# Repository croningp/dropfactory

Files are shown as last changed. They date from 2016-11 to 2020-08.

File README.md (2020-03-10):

> This repository is associated to the paper "A curious formulation robot enables the discovery of a novel protocell behavior" by Grizou, J., Points, L. J., Sharma, A. & Cronin, L. (2020) [[PDF in open Access @ Science Advances]](https://advances.sciencemag.org/content/6/5/eaay4237). An overview of the scientific approach can be found at https://jgrizou.com/projects/chemobot.

# Dropfactory

Dropfactory is a robotic platform able to perform and record oil-in-water droplet experiments at a large scale.

Dropfactory (https://www.youtube.com/watch?v=o8ZTkoZ-j6M)

Dropfactory is capable of running, in total autonomy, an arbitrary droplet experiment lasting 1min30sec every 1min50sec. We routinely performed more than 350 Experiments per working day on this platform. This enabled us to explore the efficiency of exploration and optimization algorithms directly on our physicochemical system, that is directly sampling the real world.

Here is an example of droplet behaviors:

Droplets (https://www.youtube.com/watch?v=ysEswhRS5CQ)

## Principles

The platform is organized as a little factory, enabling us to fully parallelize all required operations (mixing, droplet placing, recording, cleaning, drying). An oil-in-water experiment consists of placing small oil droplets (made from an arbitrary mixture of oils) at the surface of an aqueous medium (made from a mixture of aqueous phases), we then need to video record the droplet movements to later analyse them.

To be able to run continuously such experiments, the platform must be able to mix, sample, clean and dry both oils and aqueous phases. Previous designs had to do all such steps in sequence, Dropfactory does them in parallel thanks to its design around two geneva wheel mechanisms.

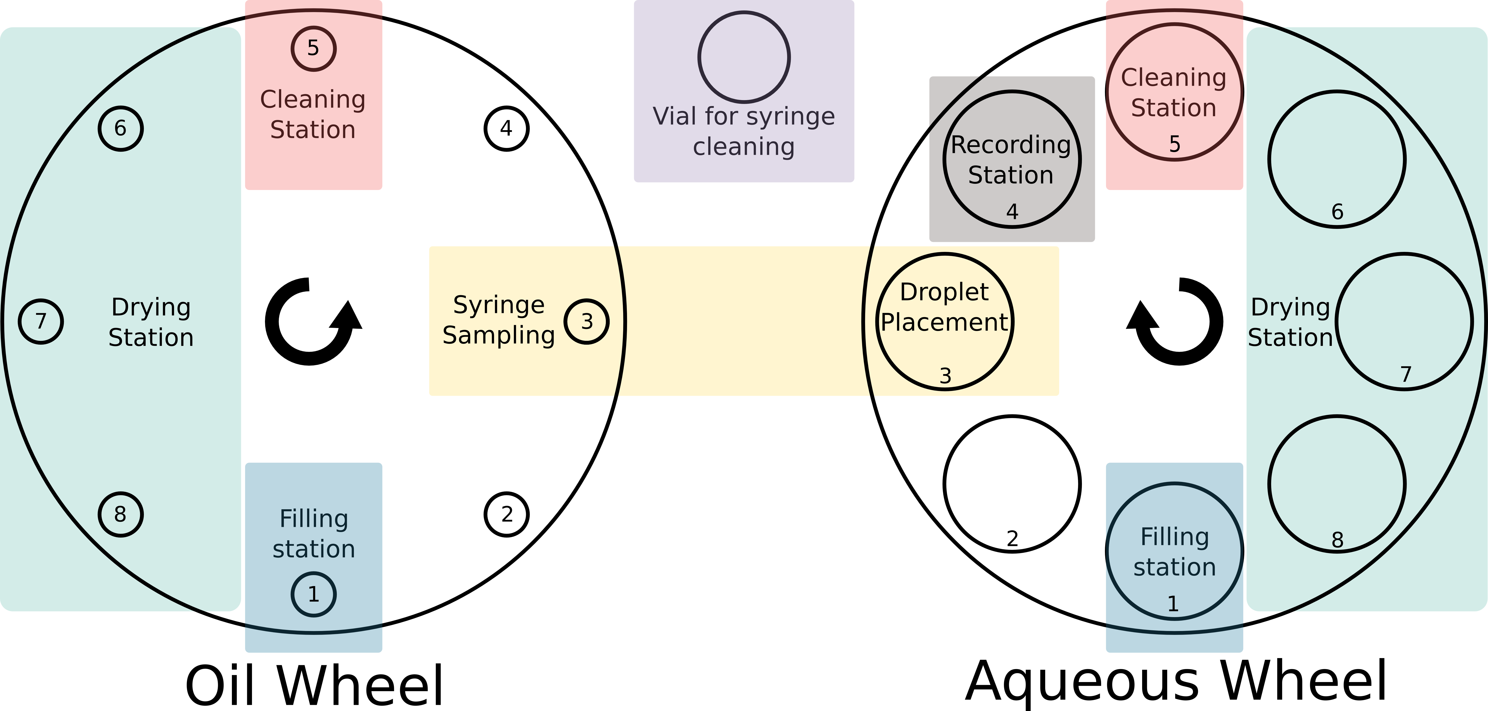
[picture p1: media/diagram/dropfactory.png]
Diagram


This design allows to move the oil vials and the petri dish at specialized working stations, rather than having the tools move to those containers. As a result, Dropfactory is:

- **robust**, because there are much less moving parts. Each working station can perform only its specific task at the location it was designed to work. This means less tubing moving around.
- **easier to maintain**, because all working stations are clearly separated, both physically and digitally, identifying a bug or a mechanical failure is quick and fixing them is easier.
- **fast**, because while an oil mixture is prepared, a previous one is being cleaned, another three are being dried, another is sampled by a syringe to be placed on a previously filled petri dish. At the same time, another petri dish is being filled, one is being cleaned, three are drying, and one contains droplets and is being recorded under a camera.

Dropfactory enables to record 1 experiment of 1min30sec every 1min50sec, gaining a factor of 6 versus our previous sequential platform. Thanks to its robustness, the platform was consistently running for months in the lab collecting more than 30,000 droplet experiments.

Below is a speed up video showing the operation of the parallelized droplet robot with details of each working station. The first few seconds gives a general overview of the working platform, whilst the remainder of the video shows each working station in operation in detail.

Dropfactory_Station (https://youtu.be/bY5OoRBJkf0)

Feel free to watch the [real time video](https://youtu.be/bY5OoRBJkf0) and [a playlist with all indivual station](https://www.youtube.com/playlist?list=PLBppiRCztuKoLdw_cc4hVg8oFJaySeC6U).

## Documentation

A detailed README is available for all folders:

- [doc](doc) folder is the place to start, it explains the logic behind all choices done in Dropfactory and contains the links to the corresponding files
- [software](software) folder holds all the python code to control and send jobs to the platform
- [hardware](hardware) folder holds all the 3D files designed for Dropfactory as well as many links to source its components.
- [media](media) folder contains some useful images and video links of the platform

This repository contains only the hardware and software used to build and operate Dropfactory. It is complemented by:

- [dropfactory_exploration](https://github.com/croningp/dropfactory_exploration) for the algorithms that use the dropfactory platform as a means to sample the real world.
- [dropfactory_analysis](https://github.com/croningp/dropfactory_analysis) for all the analysis and display of the results of our various droplets experiments and algorithms comparison.

## Author

Design and code by [Jonathan Grizou](http://jgrizou.com/) while working in the [CroninGroup](http://www.chem.gla.ac.uk/cronin/).

Thanks to Vasilis Duros and Graham Keenan for proofreading the documentation.

## License

GPL V3 (https://www.gnu.org/licenses/gpl.html)

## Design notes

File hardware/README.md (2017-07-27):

## Hardware

The [3d_parts](3d_parts) folder holds all 3D files (.stl) designed for Dropfactory. The associated [Onshape](https://www.onshape.com/) documents are accessible and fully modifiable here:

- [Platform (Frame + Geneva Wheels)](https://cad.onshape.com/documents/3aeb7616c1e547bfaae38ba3/w/426b95792e7c48a8b6dd7727/e/af7f485263ee4608affce6e3)
- [Working Stations](https://cad.onshape.com/documents/62d832e8b2dc4f2c03b85d68/w/e45d0051d41b139c7004414d/e/f1aad30ed184d979bb4387d0)
- [Geneva Wheel Stabilizer](https://cad.onshape.com/documents/5789121ee4b07256e8184139/w/a0a9bcb1b97b6c43ac68f81e/e/801990910dc3689559c2009a)
- [Printed Petri Dish](https://cad.onshape.com/documents/d83d667301ed3d6595883287/w/9d1d15f4472cf6b16456272f/e/9b20458d466fec9b558cf9b9)

The modular syringe actuator is fully described here: https://github.com/croningp/ModularSyringeDriver

Links and references to most materials used to build the platform are found in [material_references.md](material_references.md)

More details on the principles and inner working of Dropfactory are documented in the [doc](../doc) folder at the root of this repository.

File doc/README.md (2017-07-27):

The goal of this documentation is to give the reader a global understanding of the guiding principles behind the design of Dropfactory. We also aim to provide a more detailed understanding of how all the components in this repository work together.

## Principles

An oil-in-water experiment consists of placing small oil droplets (made from an arbitrary mixture of oils) at the surface of an aqueous medium (made from a mixture of aqueous phases); we then need to video record the droplet movements to later analyse them.

To be able to run continuously such experiments, the platform must be able to mix, sample, clean and dry both oils and aqueous phases. Previous designs had to do all such steps in sequence, Dropfactory does them in parallel. To do so the platform is organized as a little factory, enabling to fully parallelize all required operations (mixing, droplet placing, recording, cleaning, drying).

Diagram

To achieve this, we designed the platform around three important mechanisms:

- a [XYZ CNC frame](cnc_frame.md) that provides both the structural frame and the mechanism to move the syringe around as required to sample oil mixture and place droplets.
- two [geneva wheels](geneva_wheel.md), one for the oils, one for the aqueous phase. They allow to move the containers from one working station to another in a simple and robust way.
- [working stations](working_stations) that perform only one simple task. The vials and dishes are displaced to the working station thanks to the Geneval wheels. Having specialized working station makes the whole system easier to design, build, and fix. In addition, a lot less cables and tubes will be in motion, reducing again the possibility of failure in the system.

In addition, **we made a point to not over-design or over-specify the platform before building it**. Rather we left ourselves room for iterating on the platform while building it and as we encountered problems. For example, most working stations have been redesigned 2 or 3 times after receiving real-world feedback from practical experience.

To achieve this flexibility we based most of our design on [3D printing](https://en.wikipedia.org/wiki/3D_printing) combined with [aluminium profile](http://ooznest.co.uk/V-Slot) technology - enabling us to tune the system on site. This also explains why there is no overall 3D design specifying every detail of the platform down to the last millimetre.

**Dropfactory is a research platform, it has been conceived with modularity in mind** and we encourage the interested reader to adopt a similar approach if they are willing to build their own robot based on our design.

Below are links with more details on each sub-part of Dropfactory:

- [XYZ CNC frame](cnc_frame.md) contains information needed to build and control the XYZ system.
- [Geneva Wheel](geneva_wheel.md) explains how we designed our geneva wheel system, where the 3D files are and where the code for its control is.
- [Modular Linear Actuator](modular_linear_actuator.md) details our small modular syringe system that is used at several places in the platform (syringe + some working stations).
- [Pumps](pumps.md) explain which pumps we are using and how we control them.
- [Working Stations](working_stations) holds all the information about the design of each working station in the platform.

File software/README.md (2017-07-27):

## Software

This code implements and orchestrates all the working stations, that are specialized modules implemented as threads and able to perform one simple task well, into a fully functional platform able to accept experimental files and execute them in a parallel fashion.

The [manager.py](manager.py) file is the entry point and only file to import for using Dropfactory. It contains a ```add_XP(XP_dict)``` function that adds an experimental configuration (```XP_dict```) to the manager. The ```XP_dict``` can be created as showed in [xp_maker.py](tools/xp_maker.py).

### Experiment description

An experiment is fully described by a json file with the following fields. Note that there are helper tools to build such a file in [xp_maker.py](tools/xp_maker.py).

```python
EXAMPLE_XP_DICT = {
    # Dropfactory outputs some informaiton about the experimental conditions, such as the time of the day
    # it was run, the temperature, the humidity. The 'run_info' field tell the platform where to save
    # that information for this particualr experiment. If the experiment video will be stored place in
    # the "xp_folder" folder, a good practice is to save it at the same place.
    # By convention we use RUN_INFO_FILENAME = 'run_info.json' (see software/tools/filenaming.py)
    'run_info': {
        'filename': os.path.join(xp_folder, RUN_INFO_FILENAME)
    },
    # 'min_waiting_time' is the minimum time a dish should stay at any station,
    # this is to ensure proper drying at the drying stations.
    'min_waiting_time': 60,  # in seconds
    # 'video_info' tells the platform how long the record an experiment for and where to save that video.
    # As with he 'run_info' field, it is a good practice is to save it at the same place.
    # By convention we use VIDEO_FILENAME = 'video.avi' (see software/tools/filenaming.py)
    'video_info': {
        'filename': os.path.join(xp_folder, VIDEO_FILENAME)
        'duration': 90  # in seconds
    },
    # 'arena_type' tell what type of dish the experiment should be using. Dish should be changed manually,
    # only one dish type can be present at the same time on the platform and the ARENA_TYPE field should
    # be changed accordingly in software/constants.py. This field is mostly a security/memory field,
    # we never used other dishes that a plain glass petri_dish.
    'arena_type': 'petri_dish',
    # 'oil_formulation' describe the composition of the oil droplets.
    # The number will be normalized to sum to 1.0.
    # The association between the compounds and the associated pumps is defined in software/constants.py.
    # Changes should be reported there accordingly.
    'oil_formulation': {
        'dep': 0.36,
        'octanol': 0.29,
        'octanoic': 0.0,
        'pentanol': 0.33
    },
    ## 'surfactant_volume' how much aqueous phase to pour in the dish
    'surfactant_volume': 3.5,  # in mL
    # 'surfactant_formulation' is similar 'oil_formulation' but for the aqueous phase,
    # which can be a mixture of multiple aqueous phases. The number will be normalized to sum to 1.0.
    # As for oils, the association between the compounds and the associated pumps is defined
    # in software/constants.py. Changes should be reported there accordingly.
    'surfactant_formulation': {
        'TTAB': 1.0
    },
    # 'droplets' is the placement information for droplet, it is a list where each elements
    # corresponds to one droplet. Each droplets is then described by its 'volume' (in uL) and
    # 'position' (in mm relative to the center of the dish). Here we have 4 droplets,
    # one at the center and three equally spread around on a circle of radius 5mm.
    # DEFAULT_DROPLET_VOLUME = 4 uL.
    'droplets': [
        {
            'volume': DEFAULT_DROPLET_VOLUME, # in uL
            'position': [0, 0] # relative position in mm from the dish center
        },
        {
            'volume': DEFAULT_DROPLET_VOLUME,
            'position': [-5, 0]
        },
        {
            'volume': DEFAULT_DROPLET_VOLUME,
            'position': [2.5, 4.33]
        },
        {
            'volume': DEFAULT_DROPLET_VOLUME,
            'position': [2.5, -4.33]
        }
    ]
}
```

### Repository organization

The code is segmented by functionalities as follows:

- [arduino](arduino) holds the firmware for the two arduino boards that are used to control the entirety of the platform. It is based on our [Arduino-CommandTools](https://github.com/croningp/Arduino-CommandTools) that allows to quickly and flexibly prototype Arduino based robots.
- [pump](pump) holds the pump configurations for the 10 Tricontinent C3000 pumps used to handle liquids for droplet experiments. That is oils and aqueous phases + waste management + cleaning liquids (acetone and water). It utilises our easy to use [pycont](https://github.com/croningp/pycont) python library.
- [robot](robot) contains all the utilities to actuate the platform, such as rotating the geneva wheels or precisely pumping and delivering liquids via our syringe systems. It is based on our [commanduino](https://github.com/croningp/commanduino) tool-kit that allows to quickly and flexibly control Arduino based robots through Python.
- [tools](tools) holds various tools used to manage and organize dropfactory. The most important file is [xp_manager.py](tools/xp_manager.py) that orchestrates the parallelized operation of the robot.
- [webcam](webcam) contains the camera configuration for the MICROSOFT 6CH-00002 we use to video record the droplets. It is based on our [chemobot_tools](https://github.com/croningp/chemobot_tools) library used to detect and analyse droplets.
- [working_station](working_station) contains all the individuals working station that fulfil a single task such as cleaning the oil containers, or placing droplet with the syringe. Those stations are implemented as threads and orchestrated by the [xp_manager.py](tools/xp_manager.py) in the [tools](tools) folder.

Finally the remaining files are helpers I used while developing the platform.

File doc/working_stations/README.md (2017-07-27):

## Working stations

The platform is organized as a little factory, enabling us to fully parallelize all required operations (mixing, droplet placing, recording, cleaning, drying). An oil-in-water experiment consists of placing small oil droplets (made from an arbitrary mixture of oils) at the surface of an aqueous medium (made from a mixture of aqueous phases), we then need to video record the droplet movements to later analyse them.

To be able to run continuously such experiments, the platform must be able to mix, sample, clean and dry both oils and aqueous phases. Previous designs had to do all such steps in sequence, Dropfactory does them in parallel thanks to its design around two geneva wheel mechanisms.

Diagram

The working stations are as follows:

- [Oil filling station](oil_filling.md) prepares the correct mixture of oils in a small vial. Position 1 of the oil wheel.
- [Dish filling station](dish_filling.md) prepares the correct mixture of aqueous phase into the petri dish.  Position 1 of the aqueous wheel.
- [Oil stirring station](oil_stirring.md) makes sure the oils are properly mixed with magnetic stirrers. Position 3 of the oil wheel.
- [Droplet Placement](syringe.md) utilizes a syringe to sample the oils and dispenses them as droplet on the surface of the aqueous phase of the petri dish . Droplet sampling and placement are done on position 3 of their respective wheel.
- [Dish recording](dish_recording.md) simple record using a webcam the droplet behaviour following placement. Position 4 of the aqueous wheel.
- [Oil cleaning recording](oil_cleaning.md) cleans the oil vial so it can be reused in the next round. Position 5 of the oil wheel.
- [Dish cleaning recording](dish_cleaning.md) cleans the petri dish so it can be reused in the next round. Position 5 of the aqueous wheel.
- [Drying stations](drying.md) simply blows air on the cleaned containers to ensure they are totally dry for the next run. Drying is done on position 6, 7 and 8 of each wheel.

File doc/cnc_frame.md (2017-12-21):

## XYZ CNC Frame

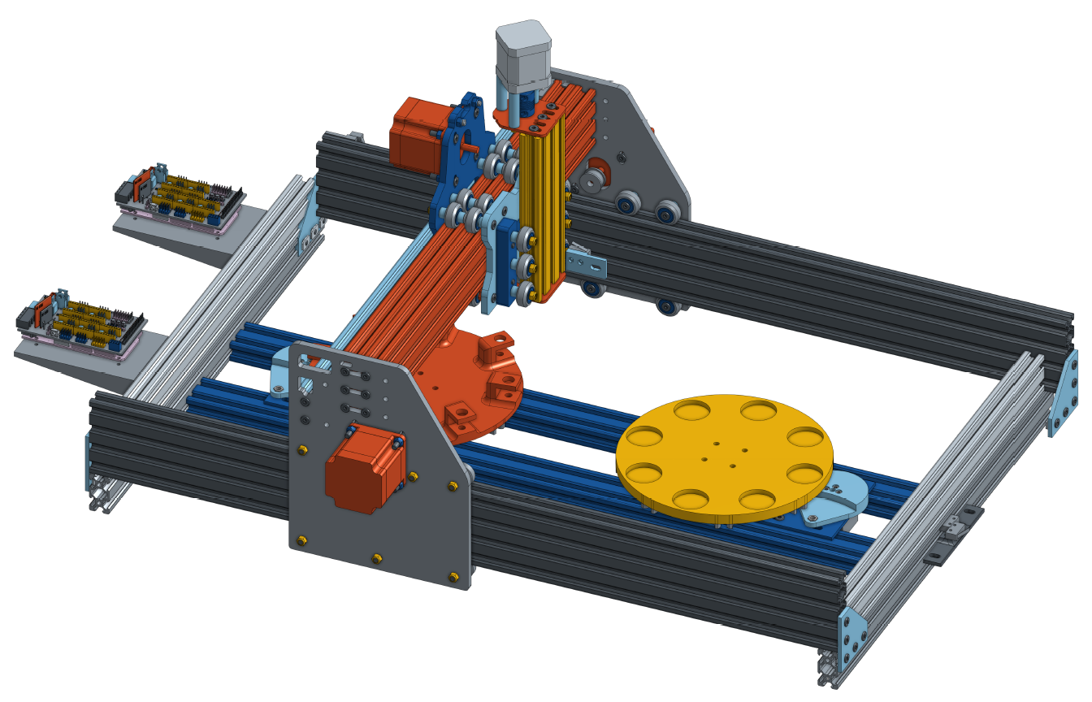
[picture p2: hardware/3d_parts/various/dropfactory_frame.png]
Frame


The XYZ is an open source CNC frame built from [aluminium profiles](http://ooznest.co.uk/V-Slot). We use the [OX CNC MECHANICAL KIT (500x750mm) + 4 NEMA 23 Stepper](http://ooznest.co.uk/3D-Printer-CNC-Kits-Bundles/OX-CNC-Machine/OX-CNC-Mechanical-Kit).

To control the XYZ motion we use two [Arduino Mega boards mounted with a Ramps 1.4 shield](http://ooznest.co.uk/3D-Printer-Electronic-Parts/RAMPS-14-Controller-Board-Premium). Each board can control 5 stepper motors, 3 are needed for the XYZ motion. 1 is needed to control our [syringe system](modular_linear_actuator.md), and 3 more to control some of our [working stations](working_stations). The board also controls our [temperature and humidity sensor](https://www.sparkfun.com/products/13683) that records the conditions under each experiment was performed.

The platform is controlled via python on an external computer using our [commanduino tool-kits](https://github.com/croningp/commanduino) allowing to quickly iterate and prototype Arduino based robots:

- the firmware for both Arduino boards is in the [software/arduino](../software/arduino) folder
- the corresponding python robot controller is in the [software/robot](../software/robot) folder

The frame design and 3D files are [available on Onshape]( https://cad.onshape.com/documents/3aeb7616c1e547bfaae38ba3/w/426b95792e7c48a8b6dd7727/e/af7f485263ee4608affce6e3)

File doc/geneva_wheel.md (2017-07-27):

## Geneva Wheels

Two Geneva wheels (1 for the oil, 1 for the aqueous phase) are at the center of the [XYZ CNC frame](cnc_frame.md), they enable to mechanically move the containers to their working station.

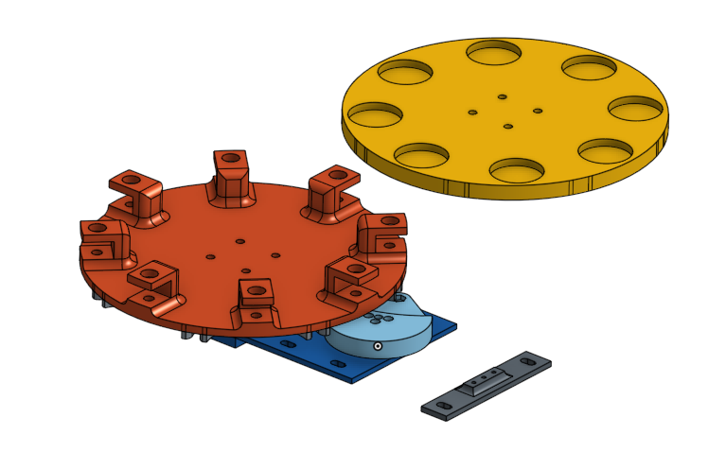
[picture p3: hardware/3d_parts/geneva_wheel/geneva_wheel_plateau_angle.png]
Genava Wheel Angle


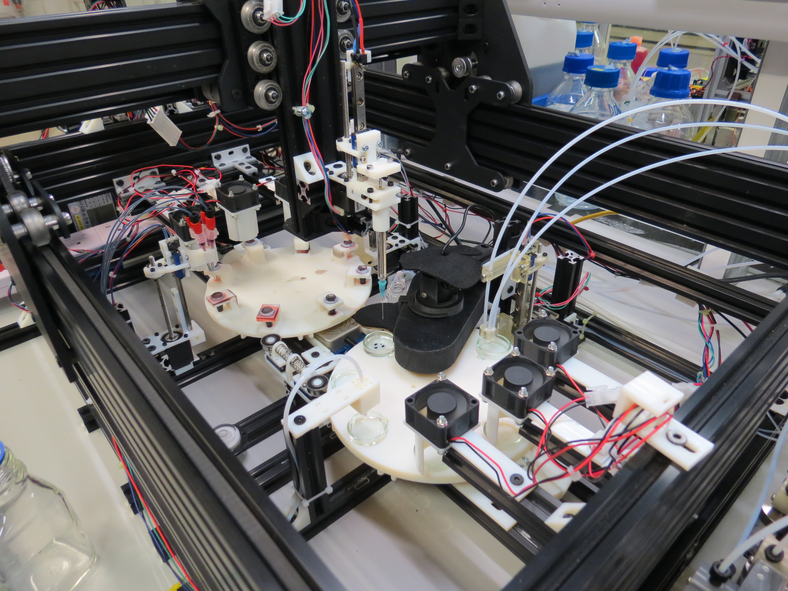
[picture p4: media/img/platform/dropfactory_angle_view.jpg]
Genava Wheel Real


### Principle

The mechanism driving a Geneva wheel provides a robust way to precisely turn a plateau step by step for a given angle from a continuous motion of the driving motor. Importantly, the plateau is mechanically locked into position between each turn. The principle is visualized in the animation below.

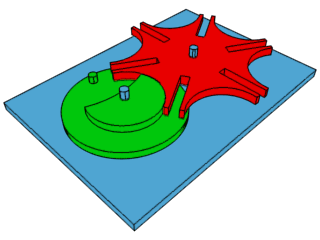
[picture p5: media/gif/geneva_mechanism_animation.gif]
Genava Wheel Gif


By <a href="//commons.wikimedia.org/wiki/User:Mike1024" title="User:Mike1024">Mike1024</a> - Transferred from <span class="plainlinks"><a class="external text" href="//en.wikipedia.org">en.wikipedia</a></span> to Commons., Public Domain, <a href="https://commons.wikimedia.org/w/index.php?curid=561907">Link</a>

Useful links:

- Wikipedia page: https://en.wikipedia.org/wiki/Geneva_drive
- Design principles:  https://newgottland.com/2012/01/08/make-geneva-wheels-of-any-size/
- Dimensioning helper: http://benbrandt22.github.io/genevaGen/

### Design

We designed our Geneva wheel system to be modular, compact, and at the same scale as our aluminium profile system, that is by multiple of 20mm.

The basic Geneva module utilizes a stepper motor that rotates the driving wheel. The rotating shaft/plateau is dimensioned to have 8 steps per turn and has some fixation patterns enabling to mount different types of plateau on top of the wheel.

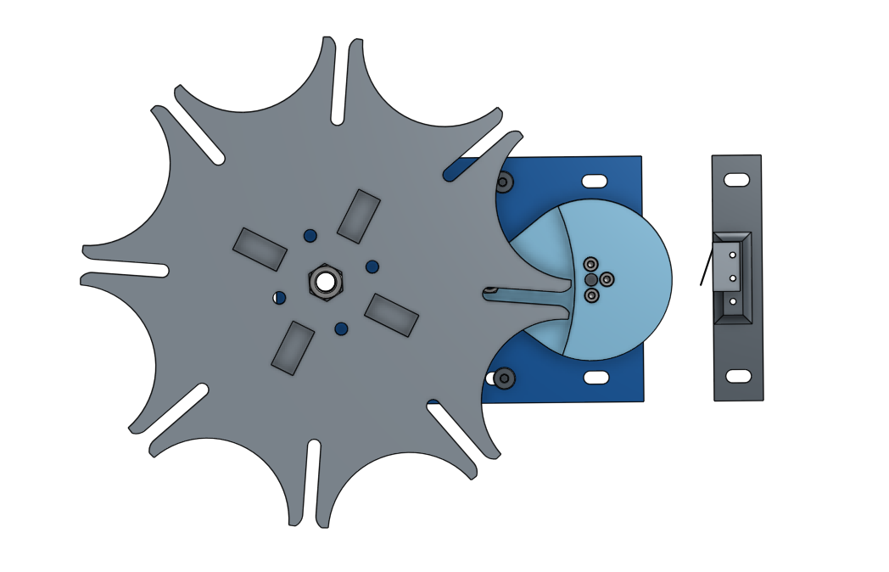
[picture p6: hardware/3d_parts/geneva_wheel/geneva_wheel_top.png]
Geneva Module Top


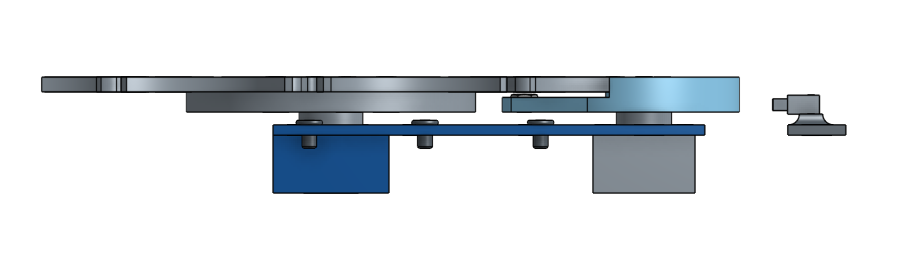
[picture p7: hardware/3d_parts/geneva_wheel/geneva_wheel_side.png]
Geneva Module Side


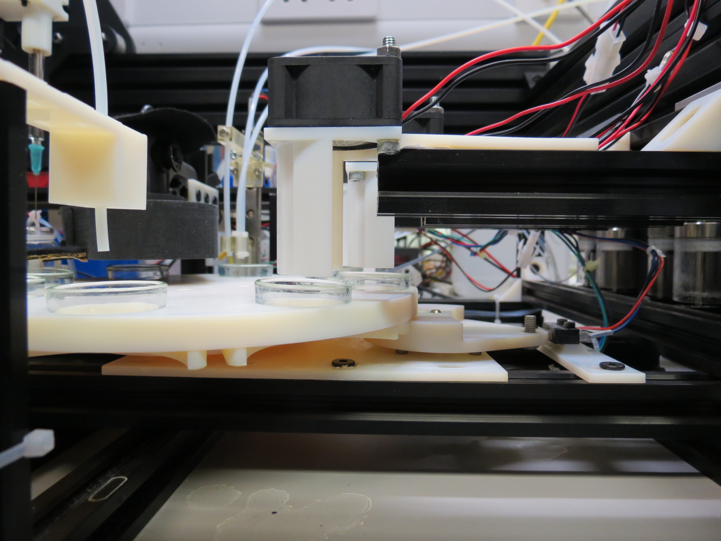
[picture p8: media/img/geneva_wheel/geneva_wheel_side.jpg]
Geneva Module Side Real


We designed two plateaus, one for handling the oil containers and one for holding the petri dishes.

Genava Wheel Angle

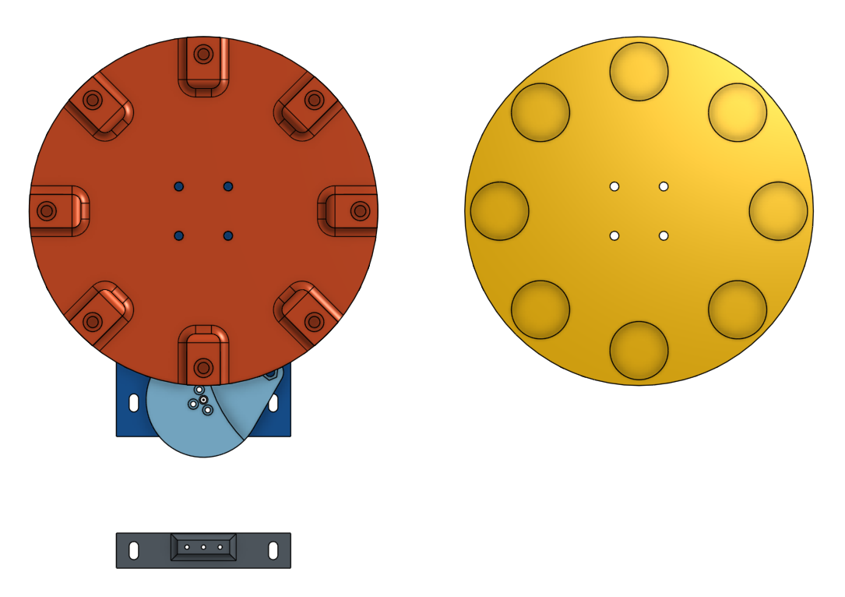
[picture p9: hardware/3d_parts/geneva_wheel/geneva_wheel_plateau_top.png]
Genava Wheel Top


Finally, to improve the smoothness of the motion we designed a stabilizer that comes into contact with both wheel and dampens possible jerks in the wheel motion. The stabilizer is made of two bearings on a sliding axis that are pushed against one another and contact with the side of the Geneva wheels, providing a slight damping that is enough to stabilize the motion.

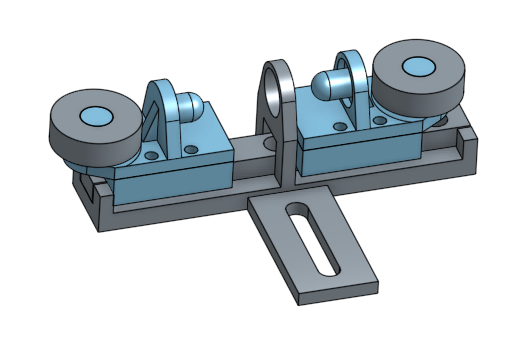
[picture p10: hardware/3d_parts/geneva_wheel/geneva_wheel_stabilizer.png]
Stabilizer


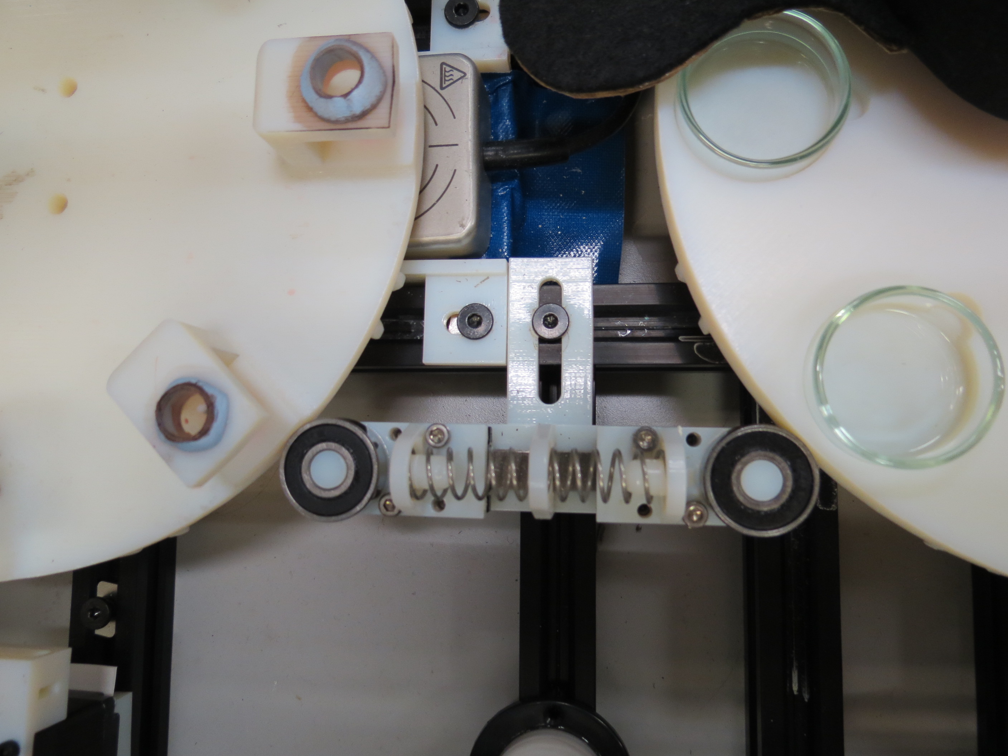
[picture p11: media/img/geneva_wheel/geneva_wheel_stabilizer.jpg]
Stabilizer Real


### Sources

All the 3d stl files are located in the [hardware/3d_parts/geneva_wheel](../hardware/3d_parts/geneva_wheel) folder, along with some visualisation of the parts.

The CAD design file are available on Onshape:

- [Geneva Wheel](https://cad.onshape.com/documents/3aeb7616c1e547bfaae38ba3/w/426b95792e7c48a8b6dd7727/e/30b62a18352c4a91b6bc9828)
- [Geneva Wheel Stabilizer](https://cad.onshape.com/documents/5789121ee4b07256e8184139/w/a0a9bcb1b97b6c43ac68f81e/e/801990910dc3689559c2009a)

The code controlling the synchronous rotation of both wheels is in the [software/robot/robot.py](../software/robot/robot.py) file, more specifically the `rotate_geneva_wheels()` function. That function first makes sure nothing is in the way of the Geneva wheels, then moves the driving stepper motor one full turn, which in turn produces a 1/8 rotation of the plateau. We ensure thhat the stepper actually does one turn by using a homing switch and raise an error if the stepper does not reach the switch within 30 seconds, indicating that the system got stuck somehow.

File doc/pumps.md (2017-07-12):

## Pumps

The platform needs to handle various liquids such as oils, aqueous phases and acetone. Our group is using [Tricontinent C-Series Syringe Pumps](https://www.tricontinent.com/products/syringe-pumps-and-rotary-valves/c-series-syringe-pumps.html). Dropfactory uses 10 of them.

Here is a top view of the pumps and the reageant containers:

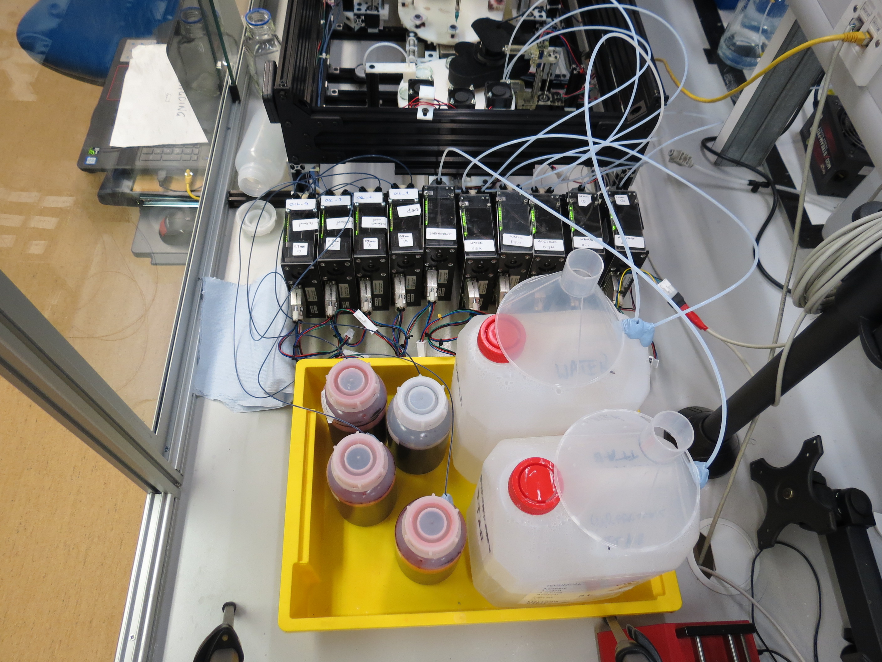
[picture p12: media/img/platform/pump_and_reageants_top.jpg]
Pumps Top


### Pump control

A full documentation of our python library to control the pumps and how to wire them is available at: https://github.com/croningp/pycont

For Dropfactory, the pumps configuration and control is managed in the [software/pump](../software/pump) folder.

### Pumps details

A pump is made of a syringe, whose volume can vary, and a valve that can dispatch the liquid from different directions.

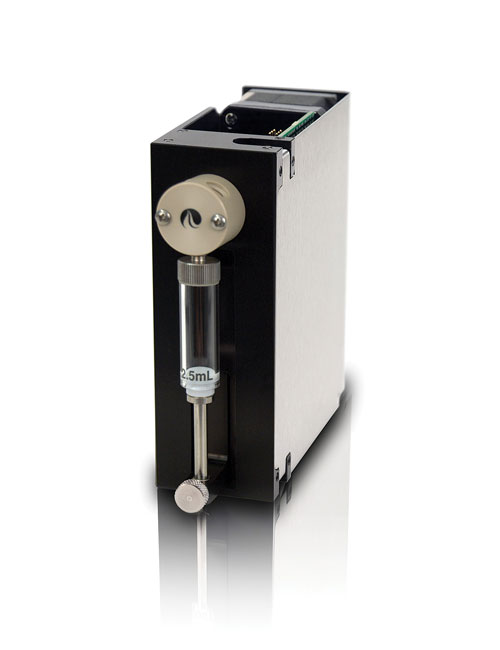
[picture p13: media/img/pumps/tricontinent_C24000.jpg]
Single Pump


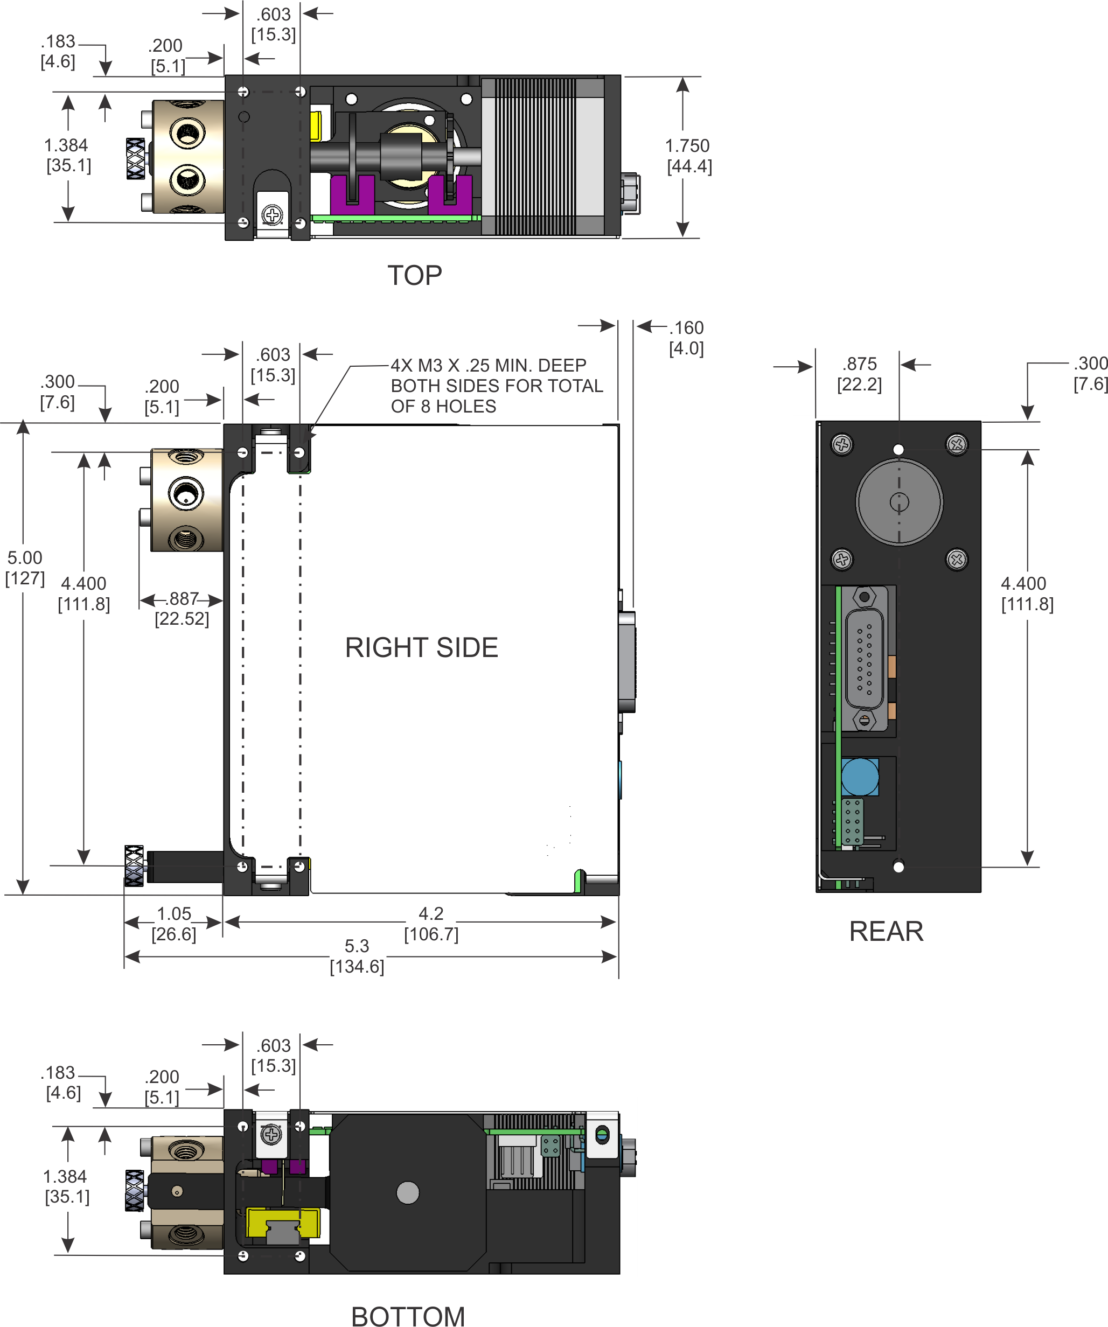
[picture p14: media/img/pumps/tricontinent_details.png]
Specs Pump


### Tubing

Here is some information about the tubing that connects to the pumps

#### Big:

1/8 inch outer diameter tubing and their fitting

- http://kinesis.co.uk/products/fittings-tubing/tubing/tubing-tubing-ptfe-1-8-3-2mm-od-x-1-5mm-id-10m-008t32-150-10.html
- http://kinesis.co.uk/flangeless-fitting-for-1-8-od-tubing-1-4-28-flat-bottom-delrin-etfe-black-yellow-xp-308.html

#### Small:

1/16 inch outer diameter tubing and their fitting

- http://kinesis.co.uk/products/fittings-tubing/tubing/tubing-tubing-ptfe-1-16-1-6mm-od-x-1-0mm-id-20m-008t16-100-20.html
- http://kinesis.co.uk/flangeless-fitting-for-1-16-od-tubing-1-4-28-flat-bottom-delrin-etfe-black-blue-xp-208.html

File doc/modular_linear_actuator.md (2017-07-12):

## Modular Linear Actuator

A full documentation of our small modular linear actuator is available on the following repository: https://github.com/croningp/ModularSyringeDriver

The appeal of this device is its modularity. Many different additions can be designed and printed as can be seen on the illustration below:

Modular Actuator Split View

This actuator is used multiple times in Dropfactory in:

- the [syringe system](working_stations/syringe.md)
- the [oil filling station](working_stations/oil_filling.md)
- the [oil cleaning station](working_stations/oil_cleaning.md)
- the [dish cleaning station](working_stations/dish_cleaning.md)

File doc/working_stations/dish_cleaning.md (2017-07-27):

## Dish Cleaning

This station handles three tubes, one to dispense water, one to dispense acetone, and one to empty the dish content to the waste. This later needs to be dipped into the dish, we use our [modular_linear_actuator](../modular_linear_actuator.md) for that.

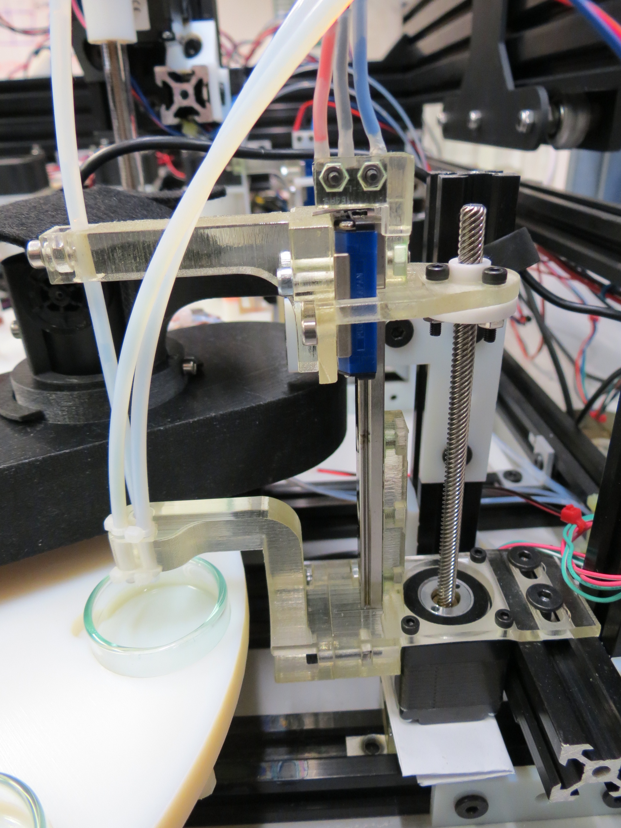
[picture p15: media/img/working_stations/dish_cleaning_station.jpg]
Dish Cleaning Real


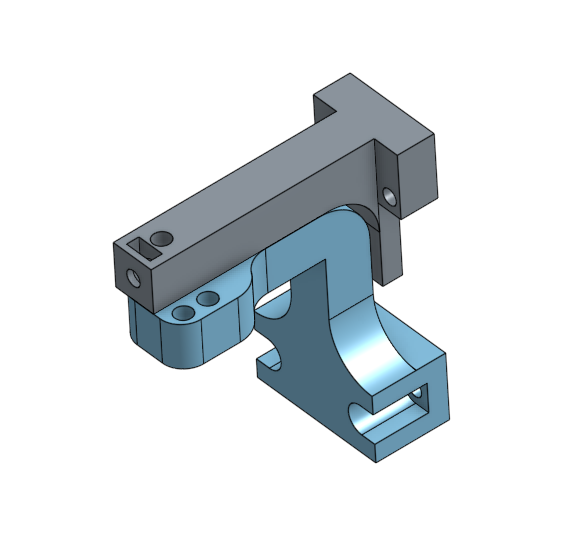
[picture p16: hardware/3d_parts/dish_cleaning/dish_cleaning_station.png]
Dish Cleaning 3D


### Procedure

A petri dish is cleaned using the following protocol:

- empty petri dish of previous experiment's content
- add 4.5mL of acetone into petri dish
- empty petri dish
- add 4.5mL of water into petri dish
- empty petri dish
- add 4.5mL of acetone into petri dish
- empty petri dish
- add 4.5mL of acetone into petri dish
- empty petri dish

### Sources

### 3D designs

- [STL Mount](../../hardware/3d_parts/dish_cleaning/dish_cleaning_mount.stl)
- [STL Guide](../../hardware/3d_parts/dish_cleaning/dish_cleaning_guide.stl)
- [Modular Actuator](https://github.com/croningp/ModularSyringeDriver)
- [Onshape 3D model](https://cad.onshape.com/documents/62d832e8b2dc4f2c03b85d68/w/e45d0051d41b139c7004414d/e/d76ad1c6bf725a9f379d21d0)

### Code

The code managing the dish cleaning working station is here: [software/working_station/clean_petri_dish.py](../../software/working_station/clean_petri_dish.py).

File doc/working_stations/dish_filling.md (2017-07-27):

## Dish Filling

This station simple holds some tubes on top of the position 1 of the aqueous wheel.

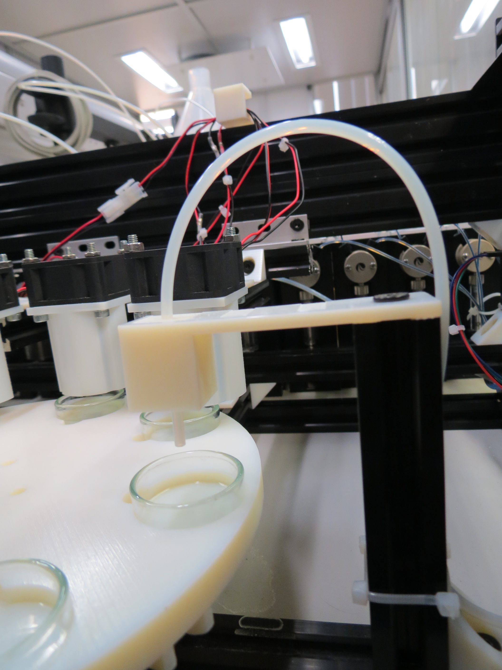
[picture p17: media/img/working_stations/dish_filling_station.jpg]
Dish Filling Real


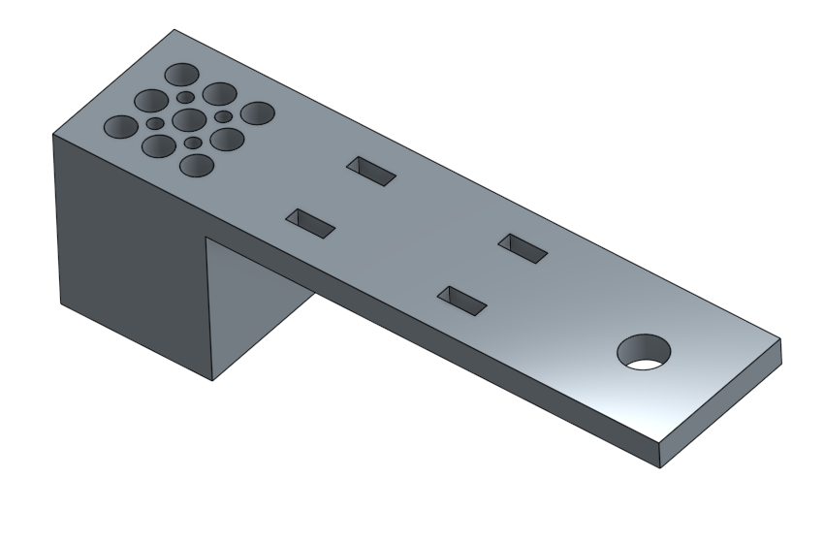
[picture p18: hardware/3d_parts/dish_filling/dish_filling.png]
Dish Filling 3D


In most of our experiments we used only one aqueous phase of TTAB at PH 13.

### Sources

### 3D designs

- [STL](../../hardware/3d_parts/dish_filling/dish_filling.stl)
- [Onshape 3D model](https://cad.onshape.com/documents/62d832e8b2dc4f2c03b85d68/w/e45d0051d41b139c7004414d/e/02edab79fbbeda28022ade23)

### Code

The code managing the dish filling working station is here: [software/working_station/fill_petri_dish.py](../../software/working_station/fill_petri_dish.py).

It simply normalizes the quantity given in the experiment description file (see [software](../../software)) and fills the dish with the given ratios of each aqueous phase given their associated pump and for the defined volume.

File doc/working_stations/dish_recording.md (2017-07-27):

## Dish Recording station

Once the droplets are placed on the aqueous phase, the dish is moved under a camera (position 4 of the aqueous wheel) for the droplet behaviour to be recorded and saved as a video file.

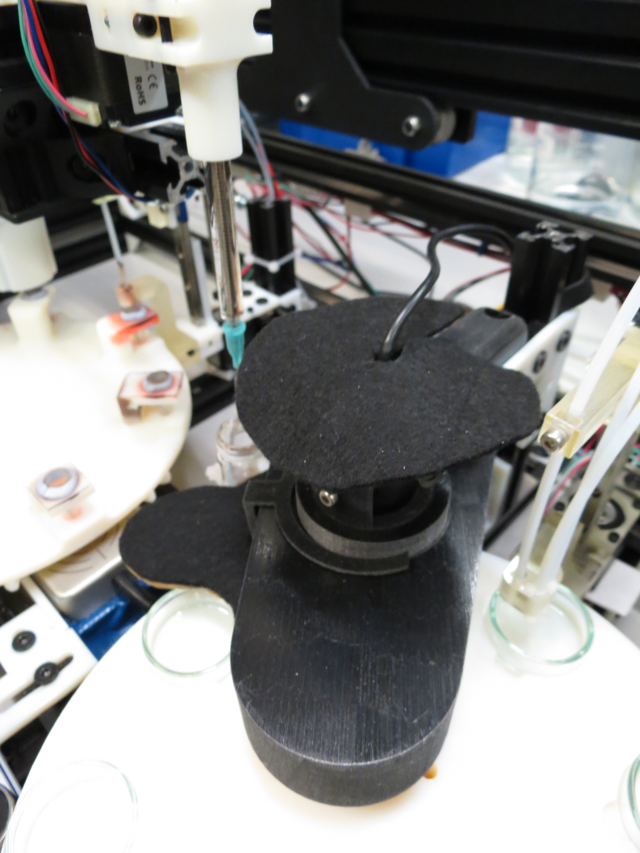
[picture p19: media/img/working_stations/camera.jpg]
Camera Real


We use a simple webcam for recording but we need to ensure that the lighting conditions are very similar between each experiment. Especially, it is important to remove all light reflection on the water surface that hinders the performance of image analysis of the droplets.

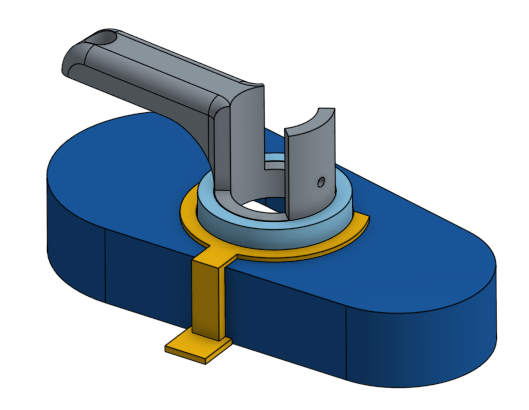
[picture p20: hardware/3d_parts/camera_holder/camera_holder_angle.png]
Camera 3D


### Sources

#### Materials

- [MICROSOFT  6CH-00002](https://www.microsoft.com/accessories/en-gb/business/lifecam-cinema-for-business/6ch-00002)

### 3D designs

- All STL files available in the [hardware/3d_parts/camera_holder](../../hardware/3d_parts/camera_holder) folder
- [Onshape 3D model](https://cad.onshape.com/documents/62d832e8b2dc4f2c03b85d68/w/e45d0051d41b139c7004414d/e/f1aad30ed184d979bb4387d0)

### Code

The code managing the camera working station is here: [software/working_station/record_video.py](../../software/working_station/record_video.py). This simply triggers the recording of a video of given duration into a specified file.

It utilizes tools from our [chemobot_tools](https://github.com/croningp/chemobot_tools) library, and is interfaced and configured in the [software/webcam](../../software/webcam) folder.

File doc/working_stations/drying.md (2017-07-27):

## Drying Station

The drying station is a simple fan blowing air into a container that was previously cleaned with water and acetone. We made sure this additional air flow did not impact our droplet experiments. The drying stations are at the position 6, 7, and 8 of both oil and aqueous wheels.

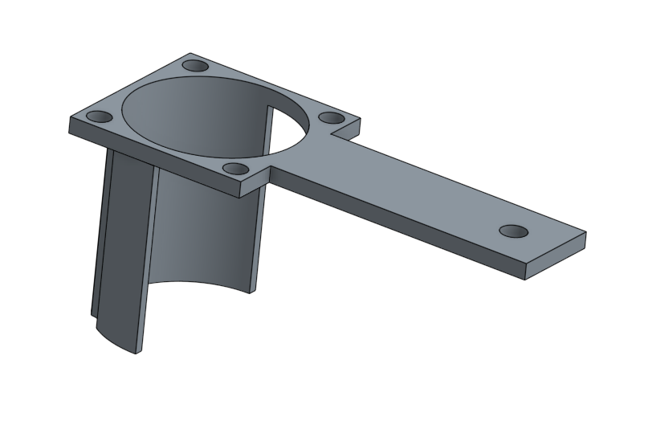
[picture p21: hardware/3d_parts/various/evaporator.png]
Drying STL


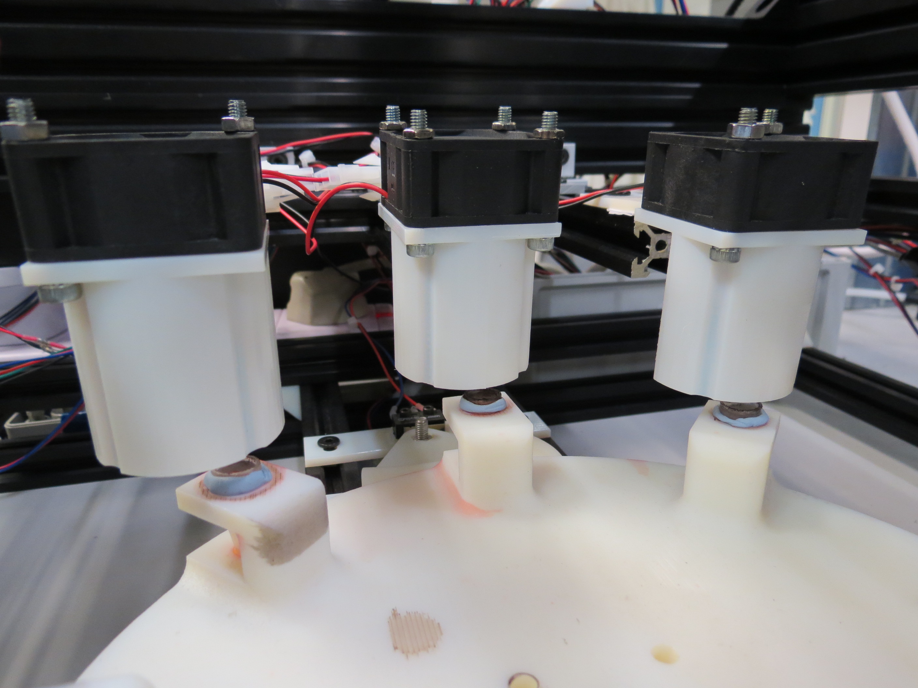
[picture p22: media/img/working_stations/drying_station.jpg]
Drying Real 1


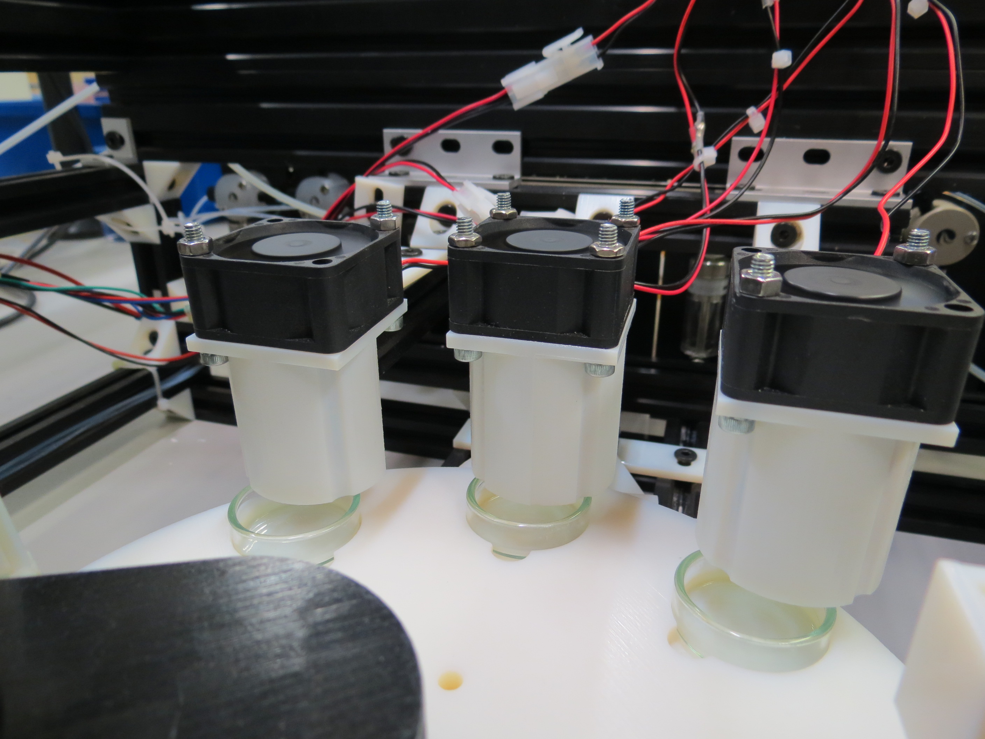
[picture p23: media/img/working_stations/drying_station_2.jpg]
Drying Real 2


### Sources

- [STL](../../hardware/3d_parts/various/evaporator.stl)
- [Onshape 3D model](https://cad.onshape.com/documents/62d832e8b2dc4f2c03b85d68/w/e45d0051d41b139c7004414d/e/ae1bb1b32d86c37772960515)

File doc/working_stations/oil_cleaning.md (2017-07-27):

## Oil Cleaning

This station handles two tubes, one to dispense acetone and one to empty the vials' content to the waste. This later needs to be dipped into the dish, we use our [modular_linear_actuator](../modular_linear_actuator.md) for that.

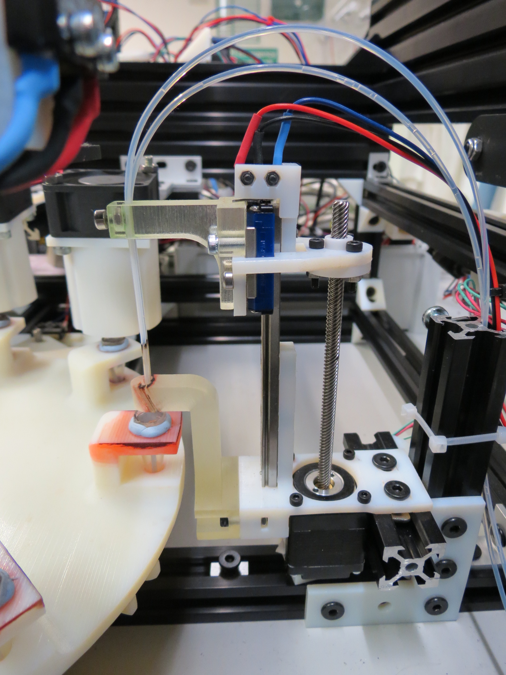
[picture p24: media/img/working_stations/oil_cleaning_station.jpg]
Oil Cleaning Real


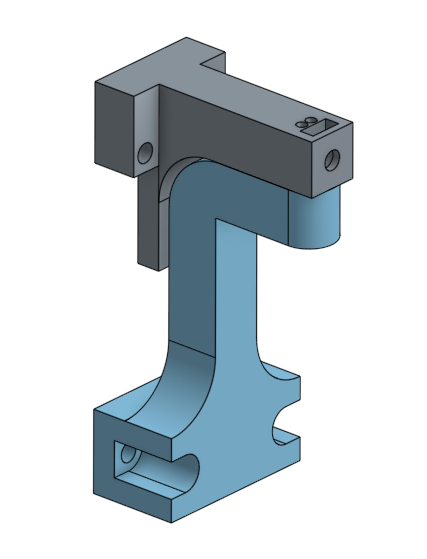
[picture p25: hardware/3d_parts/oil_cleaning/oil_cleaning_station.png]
Oil Cleaning 3D


### Procedure

An oil vial is cleaned usiing the following protocol:

- pump vial content to waste, 2mL (largely exceeding vial volume)
- repeat 5 times:
    - add 0.7mL of acetone into vial
    - pump vial content to waste, 2mL (largely exceeding vial volume)

### Sources

### 3D designs

- [STL Mount](../../hardware/3d_parts/oil_cleaning/oil_cleaning_mount.stl)
- [STL Guide](../../hardware/3d_parts/oil_cleaning/oil_cleaning_guide.stl)
- [Modular Actuator](https://github.com/croningp/ModularSyringeDriver)
- [Onshape 3D model](https://cad.onshape.com/documents/62d832e8b2dc4f2c03b85d68/w/e45d0051d41b139c7004414d/e/ba40210f0cf61fe838ccdc8a)

### Code

The code managing the oil cleaning working station is here: [software/working_station/clean_oil_parts.py](../../software/working_station/clean_oil_parts.py). This file also manages the cleaning of the syringe.

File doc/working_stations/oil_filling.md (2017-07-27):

## Oil Filling

This station handles 4 tubes, one for each of the 4 oils we used in most of our experiments. To ensure accurate dispensing, we lower down the dispnesing head into the vial using our [modular_linear_actuator](../modular_linear_actuator.md).

Oil Filling Real

Oil Filling 3D

### Procedure

- the head is lowered down so the tips of the dispensing needles comes into the vials
- the desired oils are dispensed with a given ratio to a total volume of 0.5mL
- the head is lowered down so the tips of the dispensing needles comes into contact with the surface of the oil mixture, this is to remove any pending drops remaining on the tips of the droplets
- the head comes back to its home position

### Sources

### 3D designs

- [STL Mount](../../hardware/3d_parts/oil_filling/oil_filler.stl)
- [Modular Actuator](https://github.com/croningp/ModularSyringeDriver)
- [Onshape 3D model](https://cad.onshape.com/documents/62d832e8b2dc4f2c03b85d68/w/e45d0051d41b139c7004414d/e/1583bc5599c1a1019a2f3e93)

### Code

The code managing the oil cleaning working station is here: [software/working_station/fill_oil_tube.py](../../software/working_station/fill_oil_tube.py).

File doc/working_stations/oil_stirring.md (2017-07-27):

## Oil Stirring Station

In each oil vial, there is a small magnetic stirrer. At the stirring station (position 3 of the oil wheel) a compact magnetic stirrer ensures that the oils are fully mixed before being sampled by the syringe. Such small magnetic stirrers tend to overheat, for this reason a fan has been positioned below the stirrer to regulate its temperature.

Oil Stirring

### Sources

#### Materials

- [STIRRER MICRO 07 + UK TELEMODUL 7W, from H + P LABORTECHNIK. Supplied at VWR, catalog number is 442-3116]( https://uk.vwr.com/store/product/442-3116/stirrer-micro-07-%2B-uk-telemodul-7w-1-1-items)
- [Stir bars - plain economy 4.0x0.8. Magnetic stirring bars, plain, economy. Supplied from VWR, catalog number is 442-0484](https://uk.vwr.com/store/catalog/product.jsp?catalog_number=442-0484)

#### 3D designs

- [STL Stirrer Holder](../../hardware/3d_parts/oil_mixing/stirrer_holder.stl)
- [STL Stirrer Fan Holder](../../hardware/3d_parts/oil_mixing/stirrer_fan_holder.stl)
- [Onshape 3D model](https://cad.onshape.com/documents/62d832e8b2dc4f2c03b85d68/w/e45d0051d41b139c7004414d/e/7f2bc6ac687a7f6977a3b478)

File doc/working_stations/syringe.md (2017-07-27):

## Syringe

The syringe is used for droplet placements, that is to move to collect the oil mixture, then move to the petri dish and place the droplets and finally cleans itself before moving to the next experiment. The experimental parameters are fully described in the experiment configuration file, see [software](../../software).

Syringe Front

Syringe Model

### Procedures

#### Syringe Oil Filling

- move syringe on top of oil vial (position 3 of oil wheel)
- move syringe down to dip needle into the oil
- repeat 5x: pump and release 50mL of oil mixture, this is to double ensure oils are mixed in addition of the stirrer
- pump 20uL more oil mixture than droplet making requires (total volume of requested droplets)
- move syringe up

#### Droplet Making

- move syringe on top of the center of the petri dish (position 3 of aqueous wheel)
- for each droplet defined in the config file:
    - move to given relative position, making sure it is not outside the petri dish
    - deliver given droplet volume, the droplet should not be released at this point but stick to the needle
    - move syringe down to touch the surface
    - move syringe up again above aqueous phase level
- move syringe up high above

#### Syringe Cleaning

- move syringe on top of the dedicated syringe cleaning vial
- empty syringe in the vial
- wash the vial with 1.5 mL acetone
- add 2.5mL acetone into vial
- dip needle into acetone
- repeat 3x: pump and deliver 100uL of acetone through the syringe, ensuring cleaning of remaining in oil mixture
- move syringe up again above vial
- empty vial of its contents
- repeat 8x: pump and deliver 100uL of air through the syringe, ensuring drying of remaining acetone
- wash the vial with 1 mL acetone

### Sources

### Materials

- our syringe module is compatible with all [uL Hamilton syringes](https://www.hamiltoncompany.com/products/syringes-and-needles/general-syringes/microliter-syringes/250-microL-Model-725-LT-SYR-NDL-Sold-Separately)
- we use dispensing needles of [this serie](http://uk.farnell.com/weller/kds2312p/dispensing-needle-ga23-id-0-43mm/dp/3975630), see [catalog](http://www.farnell.com/datasheets/514885.pdf).

### 3D designs

- [Modular Actuator](https://github.com/croningp/ModularSyringeDriver)
- [STL Cleaning Vial Holder](../../hardware/3d_parts/various/vial_holder.stl)
- [Onshape Cleaning Vial Holder](https://cad.onshape.com/documents/62d832e8b2dc4f2c03b85d68/w/e45d0051d41b139c7004414d/e/640ac0deb1f80bf00c4bdb79)

### Code

The code managing the syringes is split into two files:

- [software/working_station/clean_oil_parts.py](../../software/working_station/clean_oil_parts.py) for cleaning the syringes, this is because the pumps for acetone and waste are shared between the [oil vial cleaning station](oil_cleaning.md).
- [software/working_station/make_droplets.py](../../software/working_station/make_droplets.py) that takes care of the sampling of oils and the droplet placement.

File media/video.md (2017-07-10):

Videos are hosted on Youtube.

Playlist: https://www.youtube.com/playlist?list=PLBppiRCztuKoLdw_cc4hVg8oFJaySeC6U

## Platform at work

- Side View 1: https://www.youtube.com/watch?v=o8ZTkoZ-j6M
- Side View 2: https://www.youtube.com/watch?v=L7Q5ZuYX-jI
- Top View: https://www.youtube.com/watch?v=izmoXcZmUyA

## Individual workstation

- Oil Filling:https://www.youtube.com/watch?v=_yILCzj3Ur8
- Oil Cleaning: https://www.youtube.com/watch?v=vuSbGqEvNPU
- Dish Filling: https://www.youtube.com/watch?v=RBeclG4bZSc
- Dish Cleaning: https://www.youtube.com/watch?v=eZBr9EsQKLc
- Making Droplets: https://www.youtube.com/watch?v=BPY1zyb-Gb0
- Droplet Placement: https://www.youtube.com/watch?v=23sXEIOUkyw
- Syringe Cleaning: https://www.youtube.com/watch?v=D9TM6lLt240
- Pumps In Action: https://www.youtube.com/watch?v=tYG90OaSkag

## Droplets and Previous Robots

- Compilation of Droplets Behaviors: https://www.youtube.com/watch?v=ysEswhRS5CQ
- Compilation of Chemobot Platforms: https://www.youtube.com/watch?v=IiTAi5so2TA

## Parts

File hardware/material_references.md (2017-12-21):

## Generic references

Fully documented subparts:

- Our Modular Syringe Driver: https://github.com/croningp/ModularSyringeDriver
- Our Tricontinent Pump controller: https://github.com/croningp/pycont

## Platform

### Frame and kits

- OX CNC MECHANICAL KIT (500x750mm) + 4 NEMA 23 Stepper: http://ooznest.co.uk/3D-Printer-CNC-Kits-Bundles/OX-CNC-Machine/OX-CNC-Mechanical-Kit

### Control board

- Ramps 1.4, sits on top of an Arduino mega: http://ooznest.co.uk/3D-Printer-Electronic-Parts/RAMPS-14-Controller-Board-Premium?limit=100
- Wiring kit: http://ooznest.co.uk/3D-Printer-Electronic-Parts/RAMPS-1.4-Wiring-Kit?limit=100
- Switch: http://ooznest.co.uk/Micro-Lever-Switch

### Webcam

- MICROSOFT  6CH-00002: http://onecall.farnell.com/microsoft/6ch-00002/webcam-lifecam-cinema-business/dp/CS25782

### Temperature sensor

- SparkFun Humidity and Temperature Sensor Breakout - SHT15: https://www.sparkfun.com/products/13683

### Geneva Wheel

#### Stepper mount:

- https://www.proto-pic.co.uk/pololu-universal-mounting-hub-for-5mm-shaft-m3-holes-2-pack.html
- https://www.pololu.com/file/0J665/1998-5mm-m3-hub-dimensions.pdf

#### Bearings:

- http://uk.rs-online.com/web/p/ball-bearings/6189957/

#### M8 for the axis
- http://uk.rs-online.com/web/p/hex-bolts/7976288/
- http://uk.rs-online.com/web/p/hex-nuts/0530769/

#### M5
- Hex socket button: http://uk.rs-online.com/web/p/socket-screws/2328237

### Guide Chain

- http://uk.rs-online.com/web/p/cable-trunkings/3825385/
- http://uk.rs-online.com/web/p/cable-trunking-accessories/7559091

### Misc

- http://uk.farnell.com/pro-power/cv-100/cable-tie-100mm-pa66-pk100/dp/1416039
- http://uk.farnell.com/hellermanntyton/t50r-nat-100-pack/cable-tie-natural-200mm-pk100/dp/1168937

## Chemistry handling

### Mini Stirrer

- STIRRER MICRO 07 + UK TELEMODUL 7W, from H + P LABORTECHNIK. Supplied at VWR, catalog number is 442-3116: https://uk.vwr.com/store/product/442-3116/stirrer-micro-07-%2B-uk-telemodul-7w-1-1-items
- Magnetic stirring bars, micro. Length: 15mm, Diameter: 1.5mm. Supplied from VWR, catalog number is 442-0367: https://uk.vwr.com/store/catalog/product.jsp?catalog_number=442-0367

### Syringe

Hamilton Microliter syringes
- https://www.hamiltoncompany.com/products/syringes-and-needles/general-syringes/microliter-syringes/700-series/50-microL-Model-705-LT-SYR-NDL-Sold-Separately
- https://www.hamiltoncompany.com/products/syringes-and-needles/syringe-selection-tool/100-microL-m-Model-710-LT-Calibrated-SYR-NDL-Sold-Separately
- https://www.hamiltoncompany.com/products/syringes-and-needles/general-syringes/microliter-syringes/250-microL-Model-725-LT-SYR-NDL-Sold-Separately

### Blunt needle

- http://www.farnell.com/datasheets/514885.pdf
- http://uk.farnell.com/weller/kds2512p/dispensing-needle-ga25-id-0-30mm/dp/3975654
- http://uk.farnell.com/weller/kds2312p/dispensing-needle-ga23-id-0-43mm/dp/3975630

### Petri Dishes

- https://uk.vwr.com/store/catalog/product.jsp?catalog_number=BRND455701
- https://uk.vwr.com/store/catalog/product.jsp?catalog_number=391-2820

## Mixing vials

- https://webshop.fishersci.com/insight2_uk/getProduct.do?productCode=11558232&resultSetPosition=0

### Tubing

#### Big:

1/8 inch outer diameter tubing and their fitting

- http://kinesis.co.uk/products/fittings-tubing/tubing/tubing-tubing-ptfe-1-8-3-2mm-od-x-1-5mm-id-10m-008t32-150-10.html
- http://kinesis.co.uk/flangeless-fitting-for-1-8-od-tubing-1-4-28-flat-bottom-delrin-etfe-black-yellow-xp-308.html

#### Small:

1/16 inch outer diameter tubing and their fitting

- http://kinesis.co.uk/products/fittings-tubing/tubing/tubing-tubing-ptfe-1-16-1-6mm-od-x-1-0mm-id-20m-008t16-100-20.html
- http://kinesis.co.uk/flangeless-fitting-for-1-16-od-tubing-1-4-28-flat-bottom-delrin-etfe-black-blue-xp-208.html

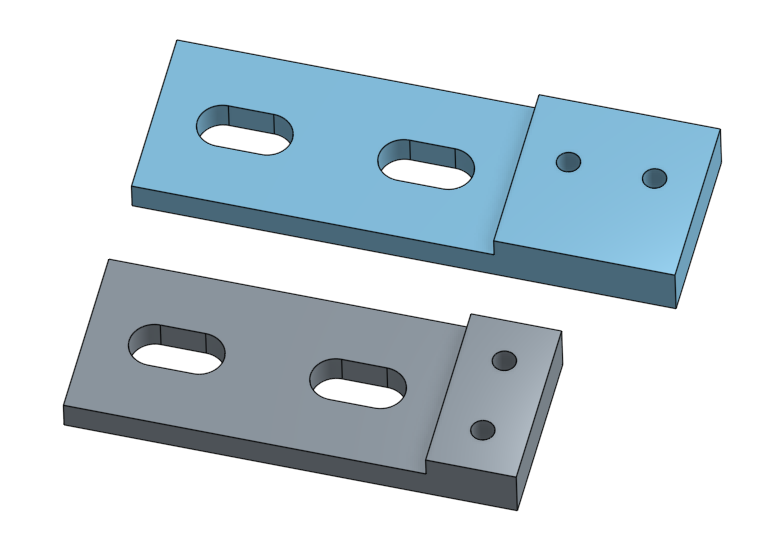
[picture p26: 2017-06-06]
hardware/3d_parts/various/switch_holder_long.png

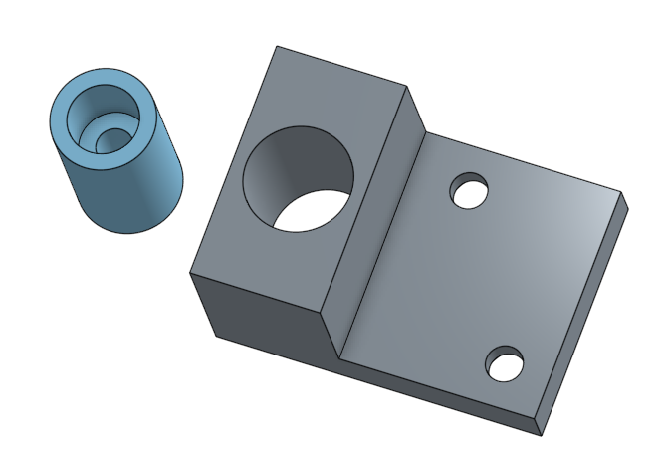
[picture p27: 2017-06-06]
hardware/3d_parts/various/chain_rotation.png

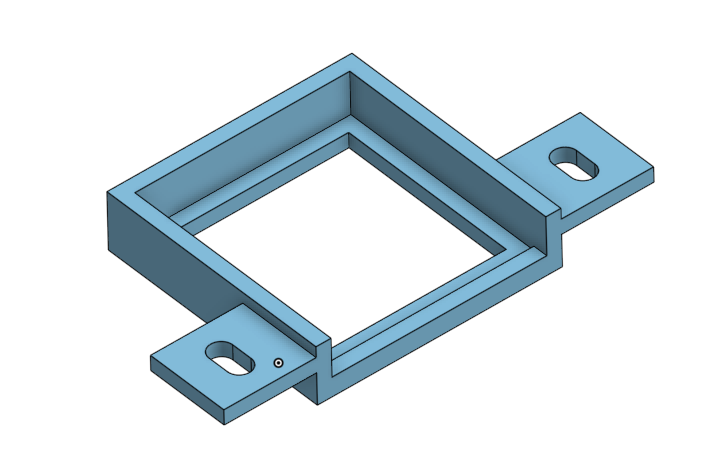
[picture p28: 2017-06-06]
hardware/3d_parts/oil_mixing/stirrer_holder.png

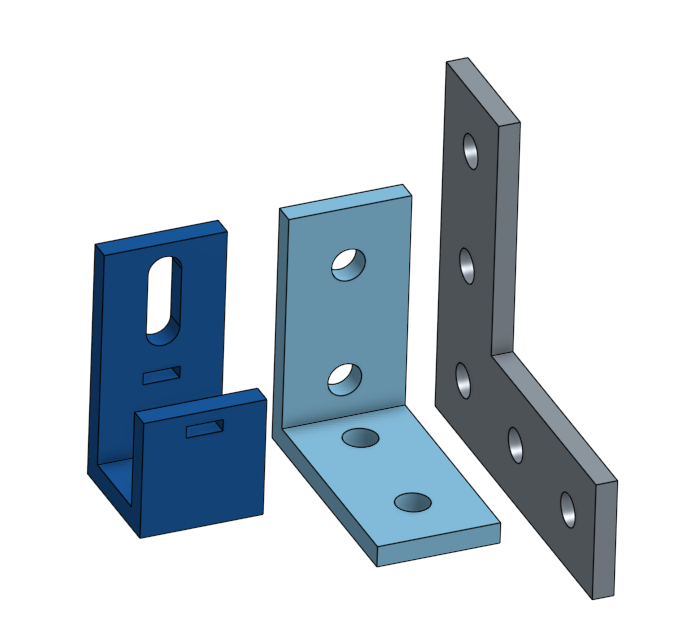
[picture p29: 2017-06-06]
hardware/3d_parts/various/vslot_tools.png

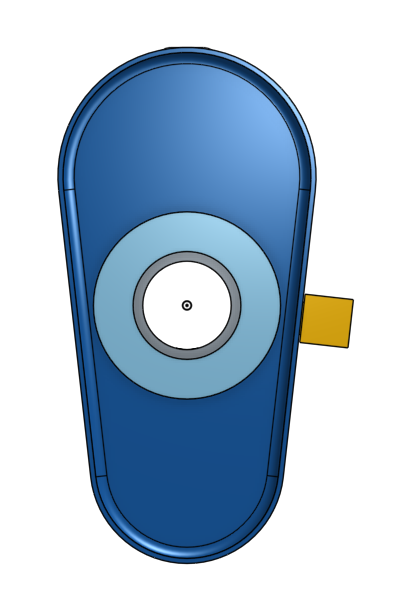
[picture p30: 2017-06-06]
hardware/3d_parts/camera_holder/camera_holder_bottom.png

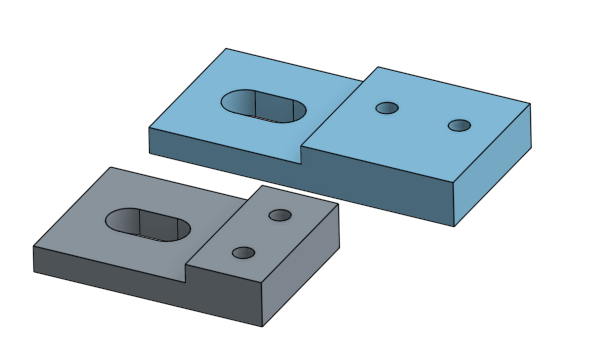
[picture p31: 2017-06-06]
hardware/3d_parts/various/switch_holder_short.png

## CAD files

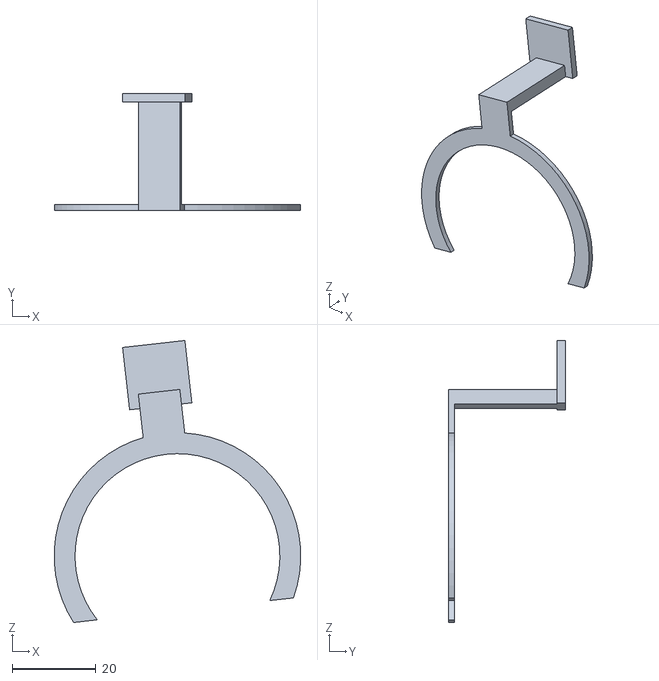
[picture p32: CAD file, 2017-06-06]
hardware/3d_parts/camera_holder/camera_shader_accessory.stl
58.9 x 28.0 x 67.5

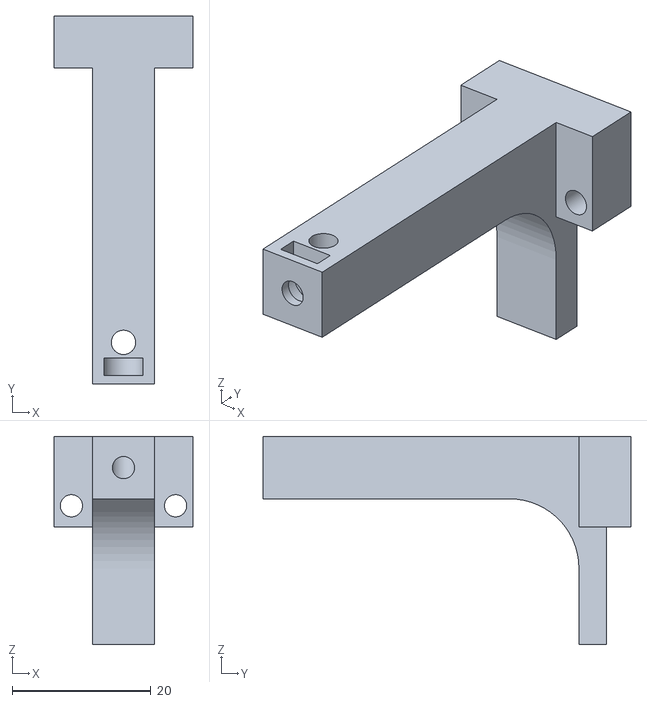
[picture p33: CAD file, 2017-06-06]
hardware/3d_parts/dish_cleaning/dish_cleaning_mount.stl
20.0 x 53.0 x 30.0

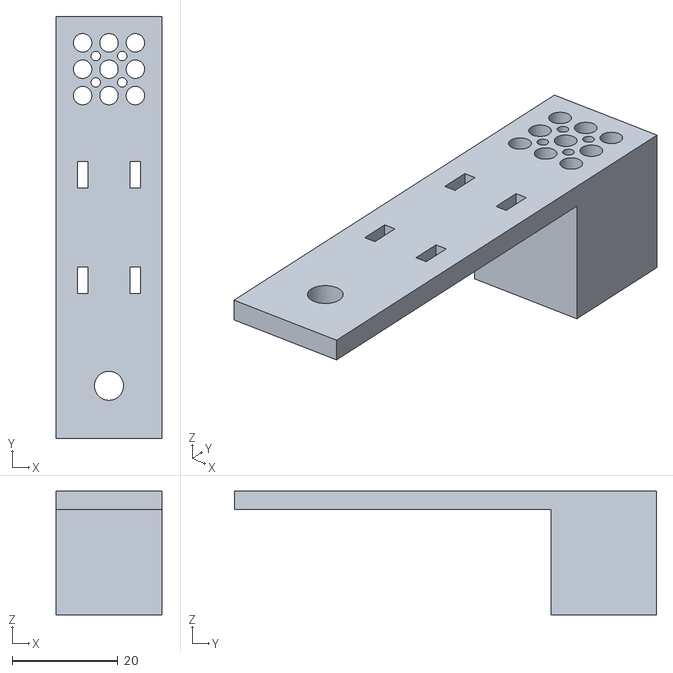
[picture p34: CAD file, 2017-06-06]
hardware/3d_parts/dish_filling/dish_filling.stl
20.0 x 80.0 x 23.5

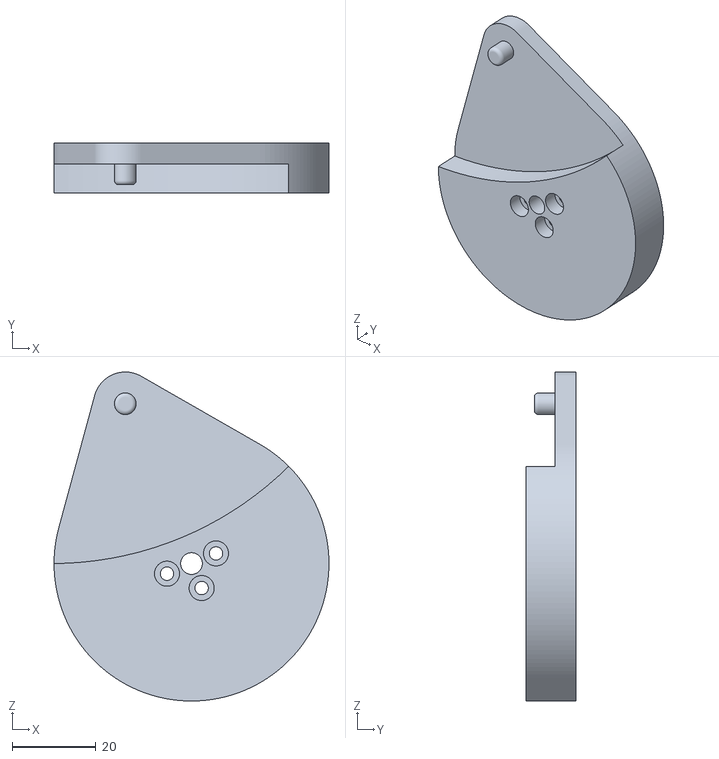
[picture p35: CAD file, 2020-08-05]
hardware/3d_parts/geneva_wheel/Geneva Wheel - rotary_part.stl
65.8 x 12.0 x 78.8

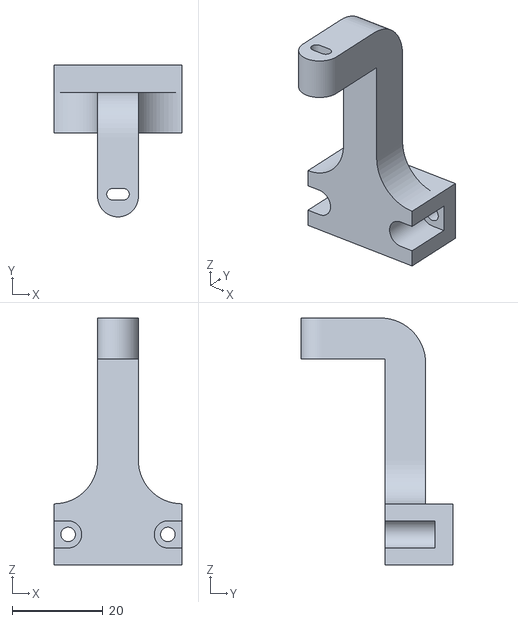
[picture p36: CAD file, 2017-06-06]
hardware/3d_parts/oil_cleaning/oil_cleaning_guide.stl
28.2 x 33.5 x 54.5

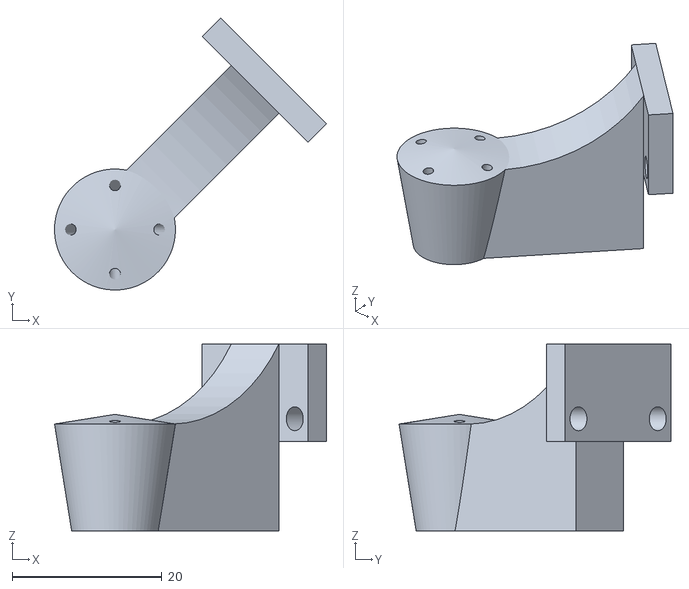
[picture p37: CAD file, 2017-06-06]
hardware/3d_parts/oil_filling/oil_filler.stl
36.4 x 36.4 x 25.0

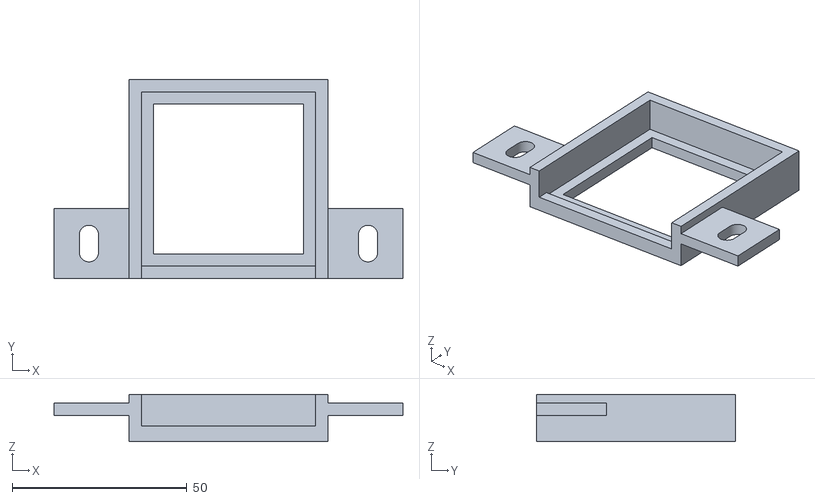
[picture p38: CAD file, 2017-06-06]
hardware/3d_parts/oil_mixing/stirrer_holder.stl
100.0 x 57.0 x 13.5

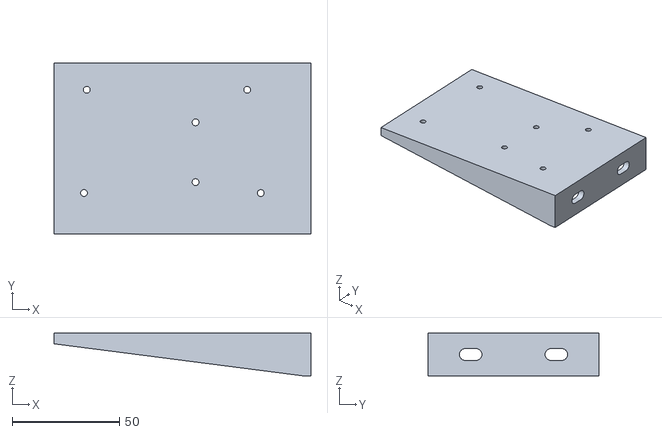
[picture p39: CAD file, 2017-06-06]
hardware/3d_parts/various/ramps_holder.stl
120.0 x 80.0 x 20.0

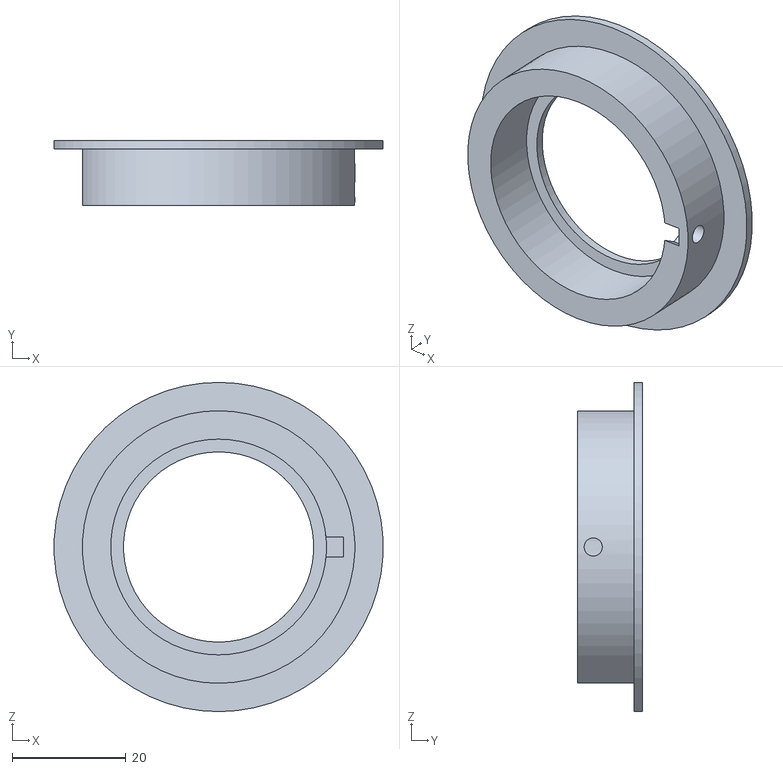
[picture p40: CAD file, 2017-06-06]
hardware/3d_parts/camera_holder/camera_holder.stl
58.0 x 11.5 x 58.0

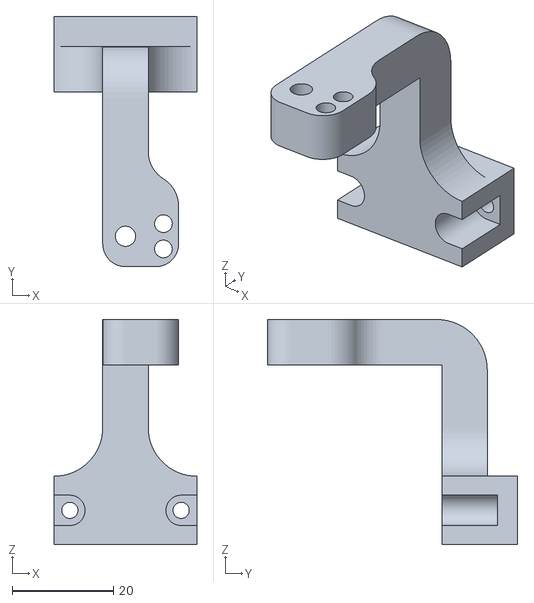
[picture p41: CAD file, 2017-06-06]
hardware/3d_parts/dish_cleaning/dish_cleaning_guide.stl
28.2 x 49.5 x 44.5

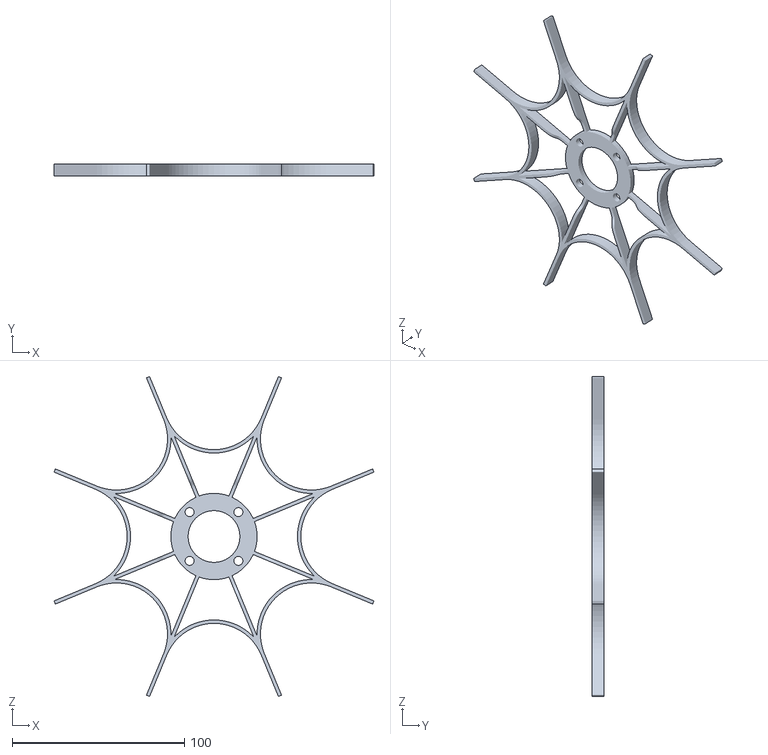
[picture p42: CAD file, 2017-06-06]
hardware/3d_parts/geneva_wheel/Geneva Wheel - light_barrier.stl
185.5 x 7.00 x 185.5

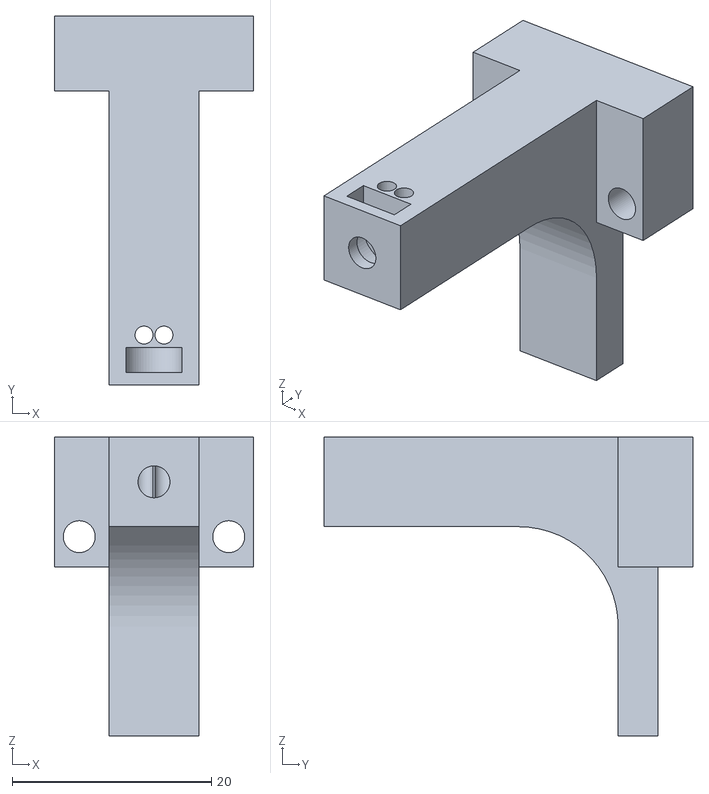
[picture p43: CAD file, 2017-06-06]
hardware/3d_parts/oil_cleaning/oil_cleaning_mount.stl
20.0 x 37.0 x 30.0

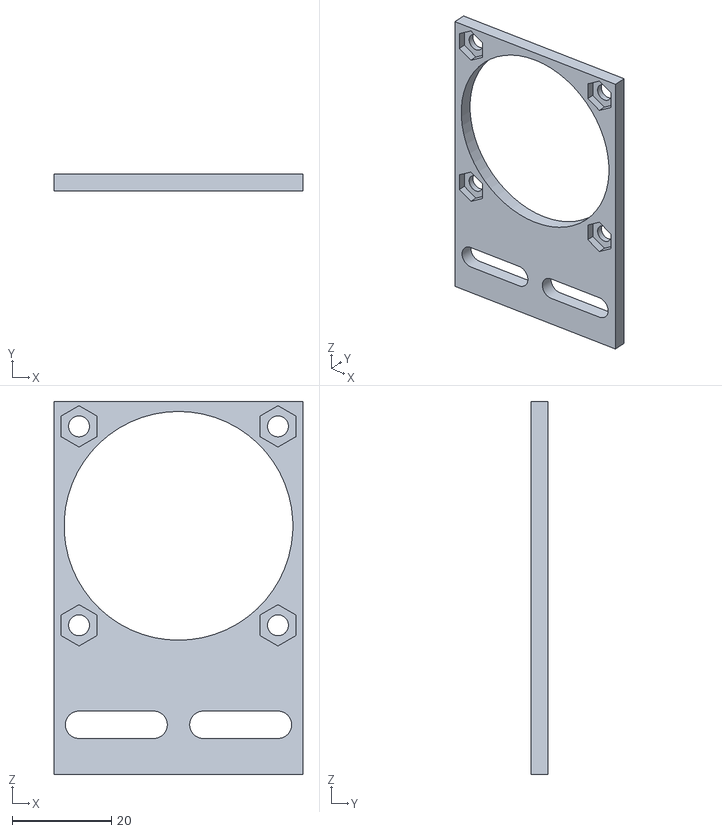
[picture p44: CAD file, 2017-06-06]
hardware/3d_parts/oil_mixing/stirrer_fan_holder.stl
50.0 x 3.50 x 75.0

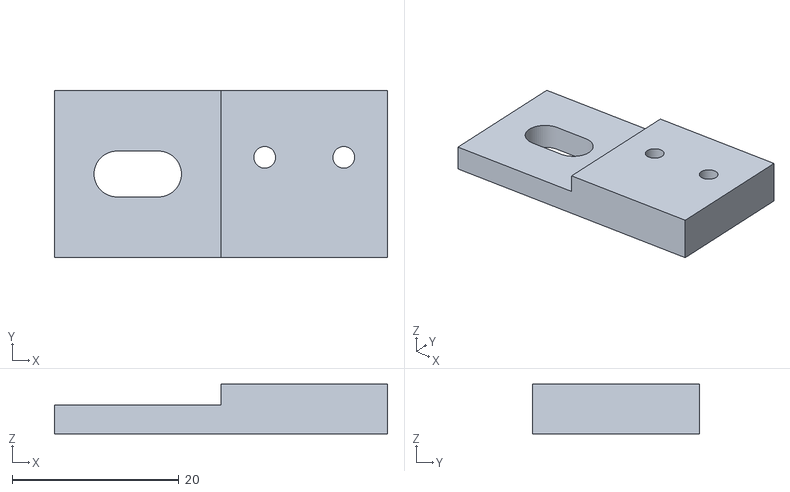
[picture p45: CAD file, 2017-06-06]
hardware/3d_parts/various/switch_holder_top_short.stl
40.0 x 20.0 x 6.00

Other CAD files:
hardware/3d_parts/camera_holder/camera_stand.stl
hardware/3d_parts/geneva_wheel/Geneva Wheel - light_damper.stl
hardware/3d_parts/various/chain_rotation_holder.stl
hardware/3d_parts/camera_holder/camera_shader.stl
hardware/3d_parts/geneva_wheel/Geneva Wheel - arena_dish_top.stl
hardware/3d_parts/geneva_wheel/Geneva Wheel - geneva_wheel.stl
hardware/3d_parts/geneva_wheel/Geneva Wheel - mixing_pot_top.stl
hardware/3d_parts/geneva_wheel/Geneva Wheel - petri_dish_top.stl
hardware/3d_parts/geneva_wheel/Geneva Wheel - switch_holder.stl
hardware/3d_parts/geneva_wheel/Geneva Wheel - vslot_mount.stl
hardware/3d_parts/geneva_wheel/Geneva Wheel Stabilizer - body.stl
hardware/3d_parts/geneva_wheel/Geneva Wheel Stabilizer - cariage.stl
hardware/3d_parts/various/ SHT15_holder.stl
hardware/3d_parts/various/block.stl
hardware/3d_parts/various/chain_rotation_axis.stl
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

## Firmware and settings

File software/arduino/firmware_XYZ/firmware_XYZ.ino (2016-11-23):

#include <CommandHandler.h>
#include <CommandManager.h>
CommandManager cmdMng;

#include <AccelStepper.h>
#include <LinearAccelStepperActuator.h>
#include <CommandLinearAccelStepperActuator.h>

AccelStepper stp_X(AccelStepper::DRIVER, 54, 55);
CommandLinearAccelStepperActuator X(stp_X, 3, 38);

AccelStepper stp_Y(AccelStepper::DRIVER, 60, 61);
CommandLinearAccelStepperActuator Y(stp_Y, 14, 56);

AccelStepper stp_Z(AccelStepper::DRIVER, 26, 28);
CommandLinearAccelStepperActuator Z(stp_Z, 18, 24);

AccelStepper stp_S1(AccelStepper::DRIVER, 36, 34);
CommandLinearAccelStepperActuator S1(stp_S1, 19, 30);


#include <SHT1X.h>
#include <CommandSHT1X.h>
CommandSHT1X SHT15(16, 17); // Data, SCK

void setup()
{
  Serial.begin(115200);

  X.registerToCommandManager(cmdMng, "X");
  Y.registerToCommandManager(cmdMng, "Y");
  Z.registerToCommandManager(cmdMng, "Z");
  S1.registerToCommandManager(cmdMng, "S1");
  SHT15.registerToCommandManager(cmdMng, "SHT15");

  cmdMng.init();
}

void loop()
{
  cmdMng.update();
}

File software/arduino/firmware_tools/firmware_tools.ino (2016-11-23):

#include <CommandHandler.h>
#include <CommandManager.h>
CommandManager cmdMng;

#include <AccelStepper.h>
#include <LinearAccelStepperActuator.h>
#include <CommandLinearAccelStepperActuator.h>

AccelStepper stp_G1(AccelStepper::DRIVER, 54, 55);
CommandLinearAccelStepperActuator G1(stp_G1, 3, 38);

AccelStepper stp_G2(AccelStepper::DRIVER, 60, 61);
CommandLinearAccelStepperActuator G2(stp_G2, 14, 56);

AccelStepper stp_S2(AccelStepper::DRIVER, 36, 34);
CommandLinearAccelStepperActuator S2(stp_S2, 19, 30);

AccelStepper stp_S3(AccelStepper::DRIVER, 46, 48);
CommandLinearAccelStepperActuator S3(stp_S3, 2, 62);

AccelStepper stp_S4(AccelStepper::DRIVER, 26, 28);
CommandLinearAccelStepperActuator S4(stp_S4, 18, 24);

void setup()
{
  Serial.begin(115200);

  G1.registerToCommandManager(cmdMng, "G1");
  G2.registerToCommandManager(cmdMng, "G2");
  S2.registerToCommandManager(cmdMng, "S2");
  S3.registerToCommandManager(cmdMng, "S3");
  S4.registerToCommandManager(cmdMng, "S4");


  cmdMng.init();
}

void loop()
{
  cmdMng.update();
}

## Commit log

2016-01-19 fisrt interation of geneva + few links
    [dropfactory - geneva_wheel.stl, dropfactory - rotary_part.stl, dropfactory - vslot_mount.stl]
2016-01-25 new version geneva wheel
    [dropfactory - geneva_wheel.stl, dropfactory - rotary_part.stl, dropfactory - vslot_mount.stl]
2016-01-26 geneva wheel top for petri dishes and mixing pot
    [dropfactory - mixing_pot_top.stl, dropfactory - petri_dish_top.stl]
2016-01-29 added syringe holder
    [Syringe_holder - base.stl, Syringe_holder - base_top.stl, Syringe_holder - puller.stl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]
2016-02-01 ramps holder
    [dropfactory - ramps_holder.stl, dropfactory - ramps_spacers.stl]
2016-02-03 new stl for endstop and misc
    [Syringue holder - micro_switch_mount.stl, VSLOT_Corner_Connectors_90Angle.stl, dropfactory - inline.stl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]
2016-02-19 was wrong firmware saved
    [firmware_XYZ.ino]
2016-03-14 calibrated platform
2016-03-21 chain holder
    [Working stations - axis.stl, Working stations - holder.stl, all_in_one.stl]
2016-03-21 working station
    [Working stations - basic_station_3_5mm.stl, Working stations - cleaning_station.stl]
2016-03-21 more working stations
    [Working stations - basic_station_3_5mm.stl, Working stations - camera_stand.stl, Working stations - cleaning_mount.stl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]
2016-04-18 docs of nema motors
2016-04-26 cable guide and syringe holder
    [Working stations - cable_guide.stl, Working stations - vials_holder.stl]
2016-05-31 pump config and relative config file
2016-05-31 cleaning syringe ok
2016-06-01 updated for new pycont init, new syringe, cleaning of all oils working
2016-06-02 remove all_in_one chain holder
    [all_in_one.stl]
2016-06-02 xp_manager beta version, to be tested on robot
    clean oil added option to clean syringe or not
2016-06-10 added motorized oil filling station and end stops for geneva wheel
2016-06-10 addapted pump config to 0.5mL syringe
2016-06-10 new stl
    [Geneva Wheel - switch_holder.stl, block - block.stl, evaporator_v2 - evaporator.stl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]
2016-06-13 light obstruction add on
    [camera_stand - light_obstruction.stl]
2016-06-13 added button to check position of servo for clean head dish
2016-06-15 change all oil pump to 3 way valve add waiting station and config min_waiting_time tuned final parameters improved manager for more info + possibility to pause
2016-06-23 added extended base to reduce syringe movement
    [syringe holder - extended_base.stl]
2016-06-24 change syringe base holder, removed blacklash
2016-07-05 fixed automatic homing problem
2016-07-05 new precision station reduce lenght to be ablt to contact better on the oil surface
    [precision_station_v2 - precision_station.stl]
2016-07-05 mounted new precision oil holder and adapted the code
2016-07-09 added an additonal error in case the oil station stepper stop working...just to avoid flooding
2016-07-13 added surfactant pump clean with water automatically clean petri dish use more acetone, we noticed some white remainings on the top of the dish, filling it more shoudl remove those residu
2016-07-27 improved cleaning sequence of syringe
2016-09-12 Changed valve of dish pump due to flooding and werid behaviors
2016-10-20 added temperature sensor in robot
2016-10-21 adding temperature and humidity recording in the run_info file
2016-11-02 changed servo for clean container
2016-11-05 start video before the homing! Otherwise one every 30 xp was recorded a bit later than the others
2016-11-22 full update of the platform remove servo cleaning to stepper based cleaning dish station pro[agted changes into the working station code reworked the shader for video solidified mecanical fixation be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
    [firmware_tools.ino]
2016-11-23 updated frimaware to have syringe with XYZ because of vibration issues
    [firmware_XYZ.ino, firmware_tools.ino]
2017-02-06 updated xp_dict to be agnostic to chemicals used, now experiments have the name of the chemicals and not the name of the pumps. The constants.py file hold the relationship between chemical names and 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
2017-02-06 adding error to check chemicals are loaded ot pumps
2017-06-06 updated properly all components and 3D files needed
    [SHT15_holder.stl, Geneva Wheel - arena_dish_top.stl, Geneva Wheel - geneva_wheel.stl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]
2017-07-12 geneva wheel
2020-07-22 Update Geneva wheel rotating part design
    [Geneva Wheel - rotary_part.stl]
